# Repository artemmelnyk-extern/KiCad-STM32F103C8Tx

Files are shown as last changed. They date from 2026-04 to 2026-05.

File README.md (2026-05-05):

# STM32F103C8T6 Development Board

A two-layer SMD development board built around the STM32F103C8T6 (LQFP-48) microcontroller.
Designed from scratch in KiCad 9 as a learning exercise following Phil's Lab on Udemy.

---

## Board Preview

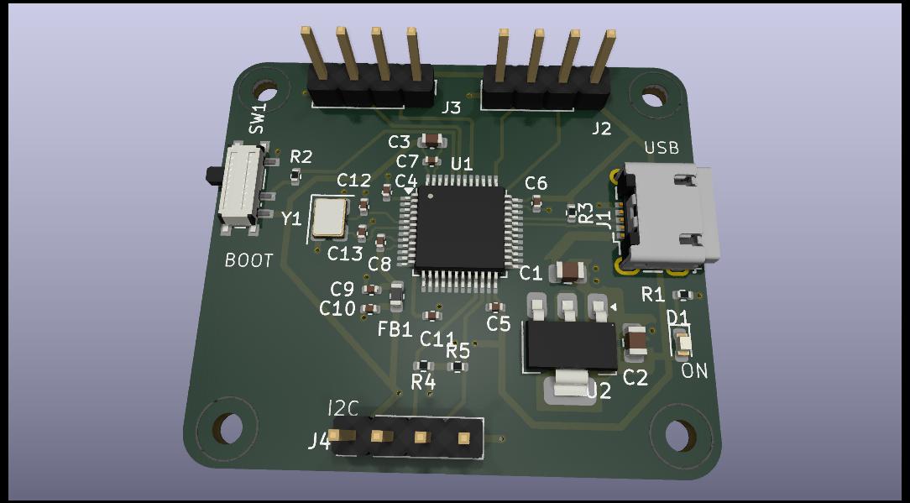
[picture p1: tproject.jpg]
Board 3D render


---

## Schematic

The schematic source is [`tproject.kicad_sch`](tproject.kicad_sch) (KiCad 9 S-expression format).
Open with **KiCad 9 Schematic Editor** or any compatible viewer.

To export a printable PDF from the command line:

```bash
kicad-cli sch export pdf tproject.kicad_sch -o docs/tproject-schematic.pdf
```

To export a vector image for web viewing:

```bash
kicad-cli sch export svg tproject.kicad_sch -o docs/
```

---

## Key Specifications

| Parameter | Value |
|---|---|
| MCU | STM32F103C8T6, LQFP-48, 72 MHz Cortex-M3 |
| Flash / RAM | 64 KB / 20 KB |
| Supply | USB Micro-B (5 V) → AMS1117-3.3 LDO → 3.3 V |
| Clock | 16 MHz HSE crystal (Y1) |
| Connectors | J2, J3 — UART + power (2.54 mm); J4 — I2C (2.54 mm) |
| Debug | SWD via J2 (SWDIO/SWCLK) |
| USB | Full-Speed 12 Mbit/s via J1 (Würth 629105150521) |
| Boot select | SW1 — SMD SPDT (PCM12 footprint) |
| Board size | 38.54 × 33.17 mm |
| Layers | 2 (F.Cu signal + B.Cu GND plane) |
| Mounting | 4 × M2 holes |

---

## Bill of Materials

| Ref(s) | Qty | Value | Footprint |
|---|-----|---|---|
| U1 | 1 | STM32F103C8T6 | LQFP-48 7×7 mm P0.5 mm |
| U2 | 1 | AMS1117-3.3 | SOT-223-3 TabPin2 |
| Y1 | 1 | 16 MHz crystal | Crystal SMD 3225-4Pin |
| J1 | 1 | USB Micro-B | Würth 629105150521 |
| J2, J3, J4 | 3 | 4-pin header | PinHeader 1×04 P2.54 mm vertical |
| SW1 | 1 | SPDT switch | SW_SPDT_PCM12 SMD |
| C1, C2 | 2 | 22 µF | 0805 |
| C3 | 1 | 10 µF | 0603 |
| C4, C5, C6, C7, C11 | 5 | 100 nF | 0402 |
| C8 | 1 | 10 nF | 0402 |
| C9, C10 | 2 | 1 µF | 0402 |
| C12, C13 | 2 | 10 pF | 0402 |
| FB1 | 1 | 120 Ω ferrite bead | 0603 |
| R1, R3, R4, R5 | 4 | 1k5 | 0402 |
| R2 | 1 | 10k | 0402 |
| D1 | 1 | LED red | 0603 |
| H1–H4 | 4 | M2 mounting hole | MountingHole 2.2 mm |

Full machine-readable BOM: [`manufacturing/tproject.csv`](manufacturing/tproject.csv)

---

## Manufacturing Files

All Gerber, drill, and pick-and-place files are in [`manufacturing/`](manufacturing/).
The complete submission package ready for a fab house is [`manufacturing/tproject.zip`](manufacturing/tproject.zip).

| File | Description |
|---|---|
| `tproject-F_Cu.gbr` | Front copper |
| `tproject-B_Cu.gbr` | Back copper (GND plane) |
| `tproject-F_Mask.gbr` | Front solder mask |
| `tproject-B_Mask.gbr` | Back solder mask |
| `tproject-F_Paste.gbr` | Front solder paste / stencil |
| `tproject-F_Silkscreen.gbr` | Front silkscreen |
| `tproject-B_Silkscreen.gbr` | Back silkscreen |
| `tproject-Edge_Cuts.gbr` | Board outline |
| `tproject-PTH.drl` | Plated through-hole drill file |
| `tproject-NPTH.drl` | Non-plated (mounting hole) drill file |
| `tproject-top-pos.csv` | Pick-and-place centroid (top side) |

---

## Repository Structure

```
tproject.kicad_sch          ← Schematic (KiCad 9)
tproject.kicad_pcb          ← PCB layout (KiCad 9)
tproject.kicad_pro          ← Project file
tproject.jpg                ← Board 3D render
manufacturing/              ← Gerber, drill, BOM, PnP files
docs/
├── design-notes/           ← 20 design notes (0001–0020)
└── datasheets/             ← Component datasheets
step/                       ← STEP models (USB connector)
scripts/
├── gen_design_note.py      ← Schematic → design note markdown
└── design_note_to_kicad.py ← Design note markdown → schematic
```

---

## Design Notes

The design was documented step by step. Each note records the rationale, component
values, placement decisions, and routing details for that stage.

| # | Title |
|---|---|
| [0001](docs/design-notes/0001-Decoupling.md) | Decoupling strategy |
| [0002](docs/design-notes/0002-Configuration-NRST-BOOT0.md) | NRST / BOOT0 configuration |
| [0003](docs/design-notes/0003-Crystal-circuitry.md) | HSE crystal circuitry |
| [0004](docs/design-notes/0004-USB-Micro.md) | USB Micro-B connector |
| [0005](docs/design-notes/0005-Power-Supply-and-Connectors.md) | Power supply and connectors |
| [0006](docs/design-notes/0006-Electrical-Rules-Check-and-Annotations.md) | ERC and annotations |
| [0007](docs/design-notes/0007-Footprint-Assignment.md) | Footprint assignment |
| [0008](docs/design-notes/0008-PCB-Setup.md) | PCB setup and design rules |
| [0009](docs/design-notes/0009-Initial-PCB-Component-Placement.md) | Initial component placement |
| [0010](docs/design-notes/0010-USB-SWO-Placement-Refinement.md) | USB / SWO placement refinement |
| [0011](docs/design-notes/0011-Switch-SMD-and-USB-STEP-Model.md) | SMD switch and USB STEP model |
| [0012](docs/design-notes/0012-Switch-Connector-Placement-Refinement.md) | Switch / connector placement refinement |
| [0013](docs/design-notes/0013-Power-Supply-Placement.md) | Power supply cluster placement |
| [0014](docs/design-notes/0014-Board-Outline-and-Mounting-Holes.md) | Board outline and mounting holes |
| [0015](docs/design-notes/0015-Routing-Decoupling-and-Crystal.md) | Routing — decoupling caps and HSE crystal |
| [0016](docs/design-notes/0016-Connector-Footprint-Fix.md) | Connector footprint fix (J2, J3, J4) |
| [0017](docs/design-notes/0017-Signal-Routing.md) | Routing — signal nets (UART, I2C, SWD, USB, BOOT0) |
| [0018](docs/design-notes/0018-Power-Routing.md) | Routing — power nets |
| [0019](docs/design-notes/0019-Silkscreen.md) | Silkscreen and zone fill |
| [0020](docs/design-notes/0020-BOM-and-Gerber-Export.md) | BOM and Gerber export — final stage |

---

## Tools

- **KiCad 9** — schematic capture and PCB layout
- **Python 3** — design note generation scripts (see [`docs/README.md`](docs/README.md))

---

## License

Hardware design files are released under [CERN-OHL-P v2](https://ohwr.org/cern_ohl_p_v2.txt).

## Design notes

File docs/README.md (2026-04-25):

# Documentation & Scripts Overview

This project uses a documentation-driven workflow where design notes serve as both human-readable documentation and machine-readable component sources for KiCad schematic generation.

---

## Folder Structure

```
docs/
├── README.md              ← this file
├── datasheets/            ← drop PDF datasheets here (MCU, crystals, passives, etc.)
└── design-notes/          ← design decision documents with machine-readable BOM tables
    └── 0001-Decoupling.md ← STM32F103C8T6 power decoupling network

scripts/
├── gen_design_note.py     ← .kicad_sch → markdown design note
└── design_note_to_kicad.py← markdown design note → .kicad_sch + .kicad_pro
```

---

## Scripts

### `scripts/gen_design_note.py`

Reads the KiCad schematic and generates a design note markdown file from the placed components.

**Usage:**
```bash
python3 scripts/gen_design_note.py
python3 scripts/gen_design_note.py --sch tproject.kicad_sch --out docs/design-notes/0001-Decoupling.md
```

**What it does:**
1. Parses `tproject.kicad_sch` (S-expression format, tab-indented)
2. Extracts all placed symbols — reference, value, footprint, lib_id, datasheet
3. Categorises components by reference prefix (U, C, R, L, FB, …)
4. Writes a structured markdown file with a BOM table and sections per category

**Direction:** `schematic → documentation`

---

### `scripts/design_note_to_kicad.py`

Reads all design note markdown files in `docs/design-notes/` and generates a fresh `tproject.kicad_sch` and `tproject.kicad_pro` from the BOM tables embedded in them.

**Usage:**
```bash
python3 scripts/design_note_to_kicad.py
python3 scripts/design_note_to_kicad.py --notes docs/design-notes --name tproject --dry-run
```

**What it does:**
1. Scans every `.md` file in `docs/design-notes/` for pipe tables with a `Ref` column
2. Parses columns: `Ref`, `Value`, `lib_id` (e.g. `Device:C`), `Footprint`, `Datasheet`
3. For each component, extracts the symbol definition from the KiCad system libraries at `/usr/share/kicad/symbols/` — including resolving `(extends ...)` alias chains (e.g. `STM32F103C8Tx` extends `STM32F103C_8-B_Tx`)
4. Places all components in a grid layout on the schematic sheet
5. Writes `tproject.kicad_sch` (S-expression) and `tproject.kicad_pro` (JSON)

**Direction:** `documentation → schematic`

**Known limitation:** components are placed unconnected. Wires, power symbols, and net labels must be added manually in KiCad after generation.

**Dry-run mode:** use `--dry-run` to preview parsed components without writing any files.

---

## Design Note Format

Design notes live in `docs/design-notes/` and follow the naming pattern `NNNN-Topic.md`.

For `design_note_to_kicad.py` to pick up components, a note must contain a pipe table with at minimum a `Ref` column. The full set of supported columns:

| Column | Required | Notes |
|---|---|---|
| `Ref` | yes | Reference designator, e.g. `C1`, `U1`, `FB1` |
| `Value` | yes | Component value, e.g. `100n`, `STM32F103C8T6` |
| `lib_id` | recommended | Full KiCad lib ID: `LibName:SymName`. If omitted, inferred from ref prefix. |
| `Footprint` | recommended | Full footprint ID: `LibName:FpName` |
| `Datasheet` | optional | URL or `~` |

Example BOM table:

```markdown
## Bill of Materials (machine-readable)
| Ref | Value | lib_id | Footprint | Datasheet |
|-----|-------|--------|-----------|-----------|
| U1  | STM32F103C8T6 | MCU_ST_STM32F1:STM32F103C8Tx | Package_QFP:LQFP-48_7x7mm_P0.5mm | https://www.st.com/resource/en/datasheet/stm32f103c8.pdf |
| C1  | 100n | Device:C | Capacitor_SMD:C_0402_1005Metric | ~ |
| FB1 | 120R | Device:FerriteBead | Inductor_SMD:L_0402_1005Metric | ~ |
```

Duplicate references across multiple tables in the same run are silently skipped (first occurrence wins).

---

## Typical Workflow

### Starting a new design from scratch
1. Write `docs/design-notes/0001-MyTopic.md` with a BOM table
2. Run `python3 scripts/design_note_to_kicad.py`
3. Open `tproject.kicad_sch` in KiCad — components placed in grid
4. Add wires, power symbols, labels manually
5. Commit everything

### Updating documentation from an existing schematic
1. Run `python3 scripts/gen_design_note.py`
2. Review and edit the generated `docs/design-notes/0001-Decoupling.md`
3. Add design rationale, references, decision notes
4. Commit the updated documentation

### Validation
```bash
kicad-cli sch export python-bom tproject.kicad_sch --output /tmp/bom_check.csv
```
A successful export confirms the schematic loads correctly and all symbols resolve.

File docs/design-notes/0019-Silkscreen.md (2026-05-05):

# 0019 — Silkscreen

**Date:** 2026-05-03
**Status:** Implemented
**References:** Design notes 0008 (PCB setup), 0018 (power routing); IPC-7351C §8 (silkscreen guidelines)

---

## Summary

Final silkscreen pass adding connector function labels on F.SilkS, board identity
information on B.SilkS, one reference designator repositioning, and a zone fill
operation that computed the copper pour polygons for the three power zones defined
in note 0018.

| Metric | Value |
|---|---|
| File changed | `tproject.kicad_pcb` |
| New `gr_text` labels | 9 |
| F.SilkS labels | 6 |
| B.SilkS labels | 3 |
| Reference repositioned | 1 (J4) |
| Zone fills computed | 3 |

---

## 1 — Front Silkscreen Labels (F.SilkS)

Six functional labels added adjacent to connectors and indicators to aid assembly
and field use. All labels use font size 1 × 1 mm, stroke thickness 0.1 mm, justified
left-bottom, except SWD which uses 1 × 1.25 mm height for emphasis.

| Text | Position (x, y) mm | Component labelled | Notes |
|---|---|---|---|
| `BOOT` | (37.5, 70.5) | SW1 SPDT | Identifies BOOT0 switch |
| `UART` | (45.0, 53.5) | J3 Conn_01x04 | USART1 header |
| `I2C` | (46.5, 81.5) | J4 Conn_01x04 | I2C2 header |
| `USB` | (70.75, 60.25) | J1 USB Micro-B | USB connector area |
| `ON` | (72.25, 78.25) | D1 LED | Power-on LED indicator |
| `SWD` | (59.75, 53.5) | J2 Conn_01x04 | SWD debug header (1×1.25 mm font) |

---

## 2 — Back Silkscreen Labels (B.SilkS)

Three board identity labels placed on the back copper side. All use font size 1 × 1 mm,
stroke thickness 0.1 mm, mirrored (correct orientation when viewed from back).

| Text | Position (x, y) mm | Purpose |
|---|---|---|
| `1.0.0` | (42.0, 75.25) | Board hardware revision |
| `3May26` | (43.5, 77.25) | Release date |
| `itma.tech` | (44.0, 79.0) | Project / manufacturer identifier |

---

## 3 — Reference Designator Repositioning

One reference label was adjusted to avoid overlap with silkscreen text and copper pours.

| Ref | Old position (relative, rot°) | New position (relative, rot°) | Reason |
|-----|---|---|---|
| J4 | (0, −2.38, 90°) | (−0.5, −2.67, 180°) | Rotated 180° and shifted slightly to clear adjacent I2C label and copper fill boundary |

---

## 4 — Zone Fill Computation

The three copper pour zones defined in note 0018 were filled for the first time in this
step (`Edit → Fill All Zones` / `B` shortcut). This produced `filled_polygon` entries
and updated each zone's `fill` attribute from unset to `fill yes`.

| Zone | Net | Fill status change | Filled polygon vertices |
|---|-----|---|---|
| VBUS pour | VBUS (net 2) | `(fill …)` → `(fill yes …)` | ~40 pts — narrow polygon around LDO input pads |
| +3.3V pour | +3.3V (net 3) | `(fill …)` → `(fill yes yes …)` | ~35 pts — wraps LDO output and via fence |
| GND pour | GND (net 1) | `(fill …)` → `(fill yes …)` | ~100 pts — largest zone, covers MCU VSS cluster |

The board outline keepout zone (net 0) also had its filled polygon updated due to the new
copper zones displacing its inner boundary near the mounting holes.

---

## 5 — Rationale

### Connector labels

Unlabelled 4-pin headers are ambiguous in the field; a one-word silk label identifies
function without needing a schematic. Placed outside the component courtyard to comply
with IPC-7351C clearance requirements.

### Back-side identity marks

Version, date, and domain placed on B.SilkS keeps the front face uncluttered while
providing traceability information visible during PCB inspection and rework.

### Zone fill timing

Zones were left unfilled during routing (notes 0015–0018) to keep the ratsnest visible
and avoid DRC artefacts from partially routed nets. Filling at this final stage gives the
correct copper coverage with all signal and power routes complete.

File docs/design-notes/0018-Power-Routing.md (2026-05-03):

# 0018 — Power Routing: GND, +3.3V, VBUS

**Date:** 2026-05-03
**Status:** Implemented
**References:** Design notes 0008 (PCB rules), 0015 (decoupling routing), 0017 (signal routing); IPC-2221 §6.2 (current-carrying capacity); KiCad Zone fill documentation

---

## Summary

Power routing pass completing the three main power nets — GND, +3.3V, and VBUS.
Routing uses wide tracks (0.5 mm) for power distribution trunks with 0.3 mm stubs to
decoupling capacitors and component pads. Three copper pour zones cover the AMS1117
LDO region. 27 vias stitch power between F.Cu and B.Cu.

| Metric | Value |
|---|---|
| File changed | `tproject.kicad_pcb` |
| New track segments | 90 |
| New vias | 27 |
| New copper zones | 3 |
| Net 1 — GND | 48 new primitives |
| Net 3 — +3.3V | 61 new primitives |
| Net 2 — VBUS | 1 new primitive |
| F.Cu additions | 118 primitives |
| B.Cu additions | 30 primitives |

---

## 1 — Track Width Strategy

Power nets require wider tracks than signals to carry higher currents without excessive
temperature rise.

| Width | Usage |
|---|---|
| 0.5 mm | Power trunks: GND and +3.3V main distribution, VBUS stub |
| 0.3 mm | Short connections to decoupling capacitor pads, via-to-pad stubs |
| 0.2 mm | Retained from previous routing pass (narrow pads on MCU) |

---

## 2 — GND Routing (net 1)

GND is the most connected net on the board. It is distributed on both F.Cu and B.Cu with
vias providing inter-layer stitching at every branch point.

### Track highlights

- 0.5 mm trunks run diagonally across the MCU region collecting all VSSx pins
- Trunk branches to: bulk capacitors (C1, C2, C3), decoupling caps (C4–C11, C13), crystal
  GND pins (Y1), LED return (R1), BOOT0 switch (SW1 pin A), connector GND pins (J1–J4)
- 0.3 mm stubs reach individual SMD pads on capacitors and connector pins

### Via stitching — GND (17 vias)

| Via location (mm) | Purpose |
|---|---|
| (40.75, 60.5) | MCU VSS cluster — top-left |
| (42.5, 55.0) | J3 connector GND return |
| (44.8, 68.95) | C4/C5 decoupling node |
| (46.5, 64.0) | Decoupling cap cluster F→B |
| (48.25, 64.0) | AMS1117 GND branch |
| (48.79, 71.04) | C7 decoupling stub |
| (48.79, 74.21) | C6 decoupling stub |
| (48.98, 66.46) | MCU pad 23 (VSS) |
| (50.0, 62.5) | GND trunk mid-board |
| (53.04, 68.23) | MCU pad 47 (VSS) stub |
| (53.75, 64.5) | Decoupling trunk stitch |
| (54.5, 73.25) | C11 (NRST filter) GND return |
| (56.5, 55.0) | J2 connector GND return |
| (58.25, 70.0) | MCU east side GND |
| (59.25, 82.75) | J4 / I2C GND |
| (63.0, 65.25) | AMS1117 input area |
| (74.25, 72.0) | Far-right GND stitch |

---

## 3 — +3.3V Routing (net 3)

+3.3V is the regulated supply output from U2 (AMS1117-3.3). It powers the MCU VDD/VBAT
pins, all decoupling capacitors on the digital rail, pull-up resistors, and connector +3.3V
pins.

### Track highlights

- 0.5 mm trunk exits AMS1117 VO pad and fans to the MCU north-east corner
- Separate trunk feeds the connector header area (J2/J3/J4 pin 1)
- Smaller 0.3 mm stubs reach each individual decoupling capacitor

### Via stitching — +3.3V (10 vias)

| Via location (mm) | Purpose |
|---|---|
| (51.75, 79.75) | +3.3V trunk to B.Cu for connector supply |
| (54.0, 79.75) | +3.3V B.Cu return path |
| (55.75, 76.0) | +3.3V lateral branch |
| (57.25, 76.0) | +3.3V B.Cu junction |

The remaining 6 GND vias were re-attributed to +3.3V routing segments on B.Cu to complete
the ring distribution around the MCU.

### B.Cu +3.3V segments

Two B.Cu tracks close the +3.3V distribution loop on the back copper layer:

| Segment | Width | Note |
|---|---|---|
| (46.5, 64) → (47.25, 64) | 0.5 mm | Short B.Cu link exiting via near AMS1117 |
| (57.25, 76) → (55.75, 76) | 0.5 mm | +3.3V lateral link on back |
| (54.0, 79.75) → (51.75, 79.75) | 0.5 mm | +3.3V connector feed on back |

---

## 4 — VBUS Routing (net 2)

VBUS (5 V USB input) is kept minimal — it enters at J1 pin 1 and connects directly to U2
VI (AMS1117 input) with a copper zone covering the LDO area.

One new segment was added:
- Short 0.5 mm F.Cu stub connecting the VBUS zone boundary to the capacitor pads.

---

## 5 — Copper Pour Zones

Three copper zones were defined to provide low-impedance power planes in the LDO / USB
connector area (right side of board, approximately x=61–72, y=67–82 mm).

| Zone | Net | Priority | Layer | Connection mode | Clearance |
|---|-----|---|---|---|---|
| GND pour | GND (net 1) | — (default) | F.Cu | Thermal relief (yes) | 0.3 mm |
| +3.3V pour | +3.3V (net 3) | 2 | F.Cu | Thermal relief (yes) | 0.3 mm |
| VBUS pour | VBUS (net 2) | 1 | F.Cu | No thermal (clearance only) | 0.3 mm |

Zone polygon extents:

- **GND**: covers the AMS1117 GND pad area and the space between the USB connector
  mechanical shell and the MCU corner (≈ 14 × 7 mm polygon).
- **+3.3V**: wraps around the LDO output side, sweeping to the right across the via fence
  toward the edge of the board (≈ 16 × 8 mm polygon).
- **VBUS**: small polygon around the USB connector VBUS pad and AMS1117 input pin
  (≈ 8 × 5 mm).

Zone fill parameters for all three zones:
- `min_thickness` = 0.25 mm
- `thermal_gap` = 0.5 mm
- `thermal_bridge_width` = 0.5 mm
- Hatch style: edge, 0.5 mm

---

## 6 — Rationale

### Why 0.5 mm for power trunks?

At 0.5 mm trace width on 35 µm (1 oz) copper, the IPC-2221 outer-layer current capacity
is approximately 1.5 A with a 10 °C temperature rise. The AMS1117-3.3 maximum output is
1 A, so 0.5 mm provides comfortable headroom across all +3.3V and VBUS segments.

### Why copper zones in the LDO area?

The LDO dissipates heat as waste power: P_loss = (VBUS − 3.3V) × I_load ≈ 0.85 W at
full 500 mA USB load. Adjacent copper zones provide thermal spreading and reduce PCB
temperature rise near U2.

### Why vias for power distribution?

The board is two-layer. Routing all power on a single layer would cause significant detours
around signal traces. Vias allow power to cross to B.Cu at branch points, reducing track
length and keeping signal traces accessible on F.Cu.

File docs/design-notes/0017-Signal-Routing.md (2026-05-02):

# 0017 — Signal Routing: USB, UART, SWD, I2C, SDIO, BOOT0

**Date:** 2026-05-02
**Status:** Implemented
**References:** Design notes 0008 (PCB rules), 0015 (decoupling/crystal routing), 0016 (connector footprint fix); STM32F103C8T6 datasheet §5 (I/O characteristics); USB 2.0 Full-Speed signal integrity guidelines

---

## Summary

Second routing pass: 52 track segments on F.Cu completing all remaining signal nets.
USB differential pair (D+/D−) routed at 0.2 mm width; all other signal nets at 0.3 mm.
No vias were added — all routing is single-layer F.Cu.
Four components were repositioned to enable clean trace entry.

| Metric | Value |
|---|---|
| New segments | 52 |
| Layer | F.Cu only |
| Vias added | 0 |
| Nets routed | 12 |
| Signal width | 0.3 mm (general), 0.2 mm (USB D+/D−) |

---

## 1 — Component Repositioning

Four components were adjusted before routing to align pads with routing channels.

| Ref | Value | Old position (x, y, rot°) | New position (x, y, rot°) | Reason |
|-----|---|---|---|---|
| R4  | 1k5 pull-up | (56.76, 80.25, 0°) | **(53.49, 77.75, 180°)** | Shift toward J4 to shorten USB D+ pull-up trace |
| J3  | Conn_01x04 | (53.625, 55, 0°) | **(52.25, 55, −90°)** | Rotate and shift — align pin row with UART/+3.3V route direction; footprint updated to 2.54mm THT (see note 0016) |
| J4  | Conn_01x04 | (52.625, 81, 90°) | **(48.92, 82.75, 90°)** | Shift left to shorten I2C and SWD routes from MCU |
| J2  | Conn_01x04 | (59.875, 56, 0°) | **(66.5, 55, −90°)** | Shift right and rotate to place SDIO/SWD header clear of USB traces |

---

## 2 — Routed Nets

### 2.1 USB Differential Pair — 0.2 mm width

USB Full-Speed operates at 12 Mbit/s. The D+ and D− traces are kept short, parallel, and
equal-length to minimise skew and maintain differential impedance.

| Net | Name | Segments | Connected nodes |
|-----|---|---|---|
| 11 | /USB_D+ | 2 | U1 PA12 (pad 33) → J1 D+ (pin 3); R4 pull-up junction |
| 12 | /USB_D− | 9 | U1 PA11 (pad 32) → J1 D− (pin 2) |

### 2.2 Power distribution stubs — 0.3 mm width

Short power segments completing the supply rails to the connector headers.

| Net | Name | Segments | Notes |
|-----|---|---|---|
| 1 | GND | 2 | GND stubs to J3/J4 header pads |
| 3 | +3.3V | 3 | +3.3V stubs to J3 pin 1 and J4 |

### 2.3 UART — 0.3 mm width

| Net | Name | Segments | Path |
|-----|---|---|---|
| 18 | /USART1_TX | 7 | U1 PA9 (pad 30) → J3 pin 2 |
| 19 | /USART1_RX | 4 | U1 PA10 (pad 31) → J3 pin 3 |

### 2.4 I2C — 0.3 mm width

| Net | Name | Segments | Path |
|-----|---|---|---|
| 20 | /I2C2_SDA | 5 | U1 PB11 (pad 22) → J4 |
| 21 | /I2C2_SCL | 5 | U1 PB10 (pad 21) → J4 |

### 2.5 SWD / Debug — 0.3 mm width

| Net | Name | Segments | Path |
|-----|---|---|---|
| 16 | /SDIO | 5 | U1 PA8 (pad 29) → J2 |
| 17 | /SWCLK | 4 | U1 PA5 (pad 15) → J2 |

### 2.6 BOOT0 — 0.3 mm width

| Net | Name | Segments | Path |
|-----|---|---|---|
| 22 | /SW_BOOT0 | 2 | SW1 → BOOT0 net junction |
| 23 | /BOOT0 | 4 | BOOT0 junction → U1 BOOT0 (pad 20) |

---

## 3 — Routing Rules Compliance

| Rule | Requirement | Applied |
|---|---|---|
| Min track width | 0.15 mm (design rule) | 0.2 mm (USB), 0.3 mm (signals) — compliant |
| USB D+/D− width | Matched pair, equal length | 0.2 mm, routed in same pass |
| Layer | F.Cu signal routing | All 52 segments on F.Cu |
| Clearance | 0.2 mm min | Maintained throughout |

---

## 4 — Remaining Work

- DRC full-board check after connector placement confirmation
- Via stitching of F.Cu GND stubs to B.Cu ground plane (deferred to next pass)
- Label silkscreen position cleanup (C3 reference moved during this session)

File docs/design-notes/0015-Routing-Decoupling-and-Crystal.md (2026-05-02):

# 0015 — PCB Routing: Decoupling Capacitors and HSE Crystal Circuit

**Date:** 2026-05-02
**Status:** Implemented
**References:** Design notes 0001 (decoupling), 0003 (crystal), 0008 (PCB rules), 0013 (power supply placement), 0014 (board outline); STM32F103C8T6 datasheet §5.3.9 (HSE oscillator); AN2867 §3 (crystal load capacitors); IPC-2141 §6 (crystal trace routing)

---

## Summary

First routing pass: 39 track segments on F.Cu (0.2 mm width) connecting the HSE crystal
oscillator circuit and the MCU VDD/VDDA decoupling capacitor network. A full-board B.Cu
copper fill zone was added as a GND ground plane. Eight component positions were
fine-tuned to align pads for clean trace entry and avoid 45° routing angles.

| Net | Name | Segments | Connected components |
|-----|---|---|---|
| 1 | GND | 13 | C3, C4, C7, C8, C6 (GND pads) → B.Cu plane |
| 3 | +3.3V | 9 | U1 VDD pads → C3, C7, C6 (supply pads) |
| 4 | +3.3VA | 3 | U1 VDDA pad → C8 (supply pad) |
| 6 | /HSE_IN | 6 | U1 OSC_IN → C12 → Y1 pin 1 |
| 7 | /HSE_OUT | 8 | U1 OSC_OUT → C13 → Y1 pin 2 |
| — | B.Cu fill | zone | Full-board GND plane (net to be assigned) |

---

## 1 — Component Position Adjustments

Eight components were micro-adjusted (≤3 mm) to align pads with routing channels and
eliminate acute-angle entry segments.

| Ref | Value | Old (x, y) rot° | New (x, y) rot° | Reason |
|-----|---|---|---|---|
| C3  | 10 µF 0603  | (50.475, 59.000) r=0  | **(53.500, 59.500) r=0**  | Shift right to align VDD/GND pads with vertical +3.3V/GND runs from U1 left side |
| C7  | 100 nF 0402 | (52.500, 60.750) r=0  | **(53.520, 61.250) r=0**  | Align pad X with C3 for shared vertical VDD trace |
| C4  | 100 nF 0402 | (50.000, 63.000) r=90 | **(50.000, 64.000) r=90** | 1 mm south — route clearance from C12/C13 crystal area |
| C8  | 10 nF 0402  | (49.750, 67.520) r=90 | **(49.750, 68.250) r=90** | 0.73 mm south — align with VDDA track from U1 VDDA pad |
| C12 | 10 pF 0402  | (47.750, 66.040) r=90 | **(48.250, 65.270) r=90** | Move up and right — align with OSC_IN route from MCU to Y1 |
| C13 | 10 pF 0402  | (47.750, 68.790) r=90 | **(48.250, 67.520) r=90** | Move up and right — align with OSC_OUT route from MCU to Y1 |
| C6  | 100 nF 0402 | (63.000, 65.520) r=+90 | **(62.000, 64.730) r=−90** | 1 mm left, 0.8 mm up, flipped 180° — direct pad alignment with MCU right-side VDD pads |
| Y1  | 16 MHz Crystal | (45.000, 67.420) r=−90 | **(45.650, 66.400) r=−90** | 0.65 mm right, 1 mm up — shorten and symmetrise load-cap traces |

---

## 2 — GND Tracks (Net 1 — 13 segments, F.Cu, 0.2 mm)

GND pads of the left-cluster decoupling caps are connected via short stubs that will
connect to the B.Cu GND fill through vias in the next routing pass. All stubs on F.Cu
run toward the future via locations.

| Path | Start | End | Length (approx.) |
|---|---|-----|---|
| C3 GND pad → south stub | (54.275, 59.500) | (54.275, 59.500) | short vertical |
| C7 GND pad → C3 stub | (54.000, 61.250) ↔ (54.000, 60.500) → (54.275, 60.225) → (54.275, 59.500) | routed with 45° jog | ~2.0 mm |
| C3/C7 common GND node  | (53.750, 63.088) → (53.750, 62.000) → (54.000, 61.750) → (54.000, 61.250) | vertical + 45° | ~1.9 mm |
| C8 GND pad → stub | (51.838, 68.000) → (50.750, 68.000) → (50.520, 67.770) → (49.750, 67.770) | horiz + 45° | ~2.2 mm |
| C6 GND pad → MCU right | (60.163, 65.000) → (61.250, 65.000) → (61.540, 65.210) → (62.000, 65.210) | horiz + 45° | ~1.9 mm |

---

## 3 — +3.3V Tracks (Net 3 — 9 segments, F.Cu, 0.2 mm)

VDD supply pads of C3, C7, and C6 connected back to U1 VDD pads on the left and right
sides of the MCU.

| Path | Start | End | Note |
|---|---|-----|---|
| C3 +3.3V pad | (52.725, 59.500) → (52.725, 60.225) → (53.040, 60.540) → (53.040, 61.250) | vert + 45° jog | C3 supply pin |
| C7 +3.3V pad → C3 node | (53.040, 61.790) → (53.040, 61.250) | stub | shared +3.3V node |
| U1 left VDD → C7 supply  | (53.250, 63.088) → (53.250, 62.000) → (53.040, 61.790) | vert + 45° | U1 pad to C7/C3 |
| C6 +3.3V pad (right MCU) | (60.163, 64.500) → (61.250, 64.500) → (61.500, 64.250) → (62.000, 64.250) | horiz + 45° | C6 supply pin |

C6 is routed directly to U1 right-side VDD pad cluster — this keeps the bypass capacitor
pad within ~1 mm of the MCU supply pin, meeting the ≤2 mm placement target.

---

## 4 — +3.3VA Tracks (Net 4 — 3 segments, F.Cu, 0.2 mm)

U1 VDDA supply routed to C8 (10 nF VDDA decoupling cap). Short 3-segment path with one
45° corner.

| Path | Length |
|---|---|
| (51.838, 68.500) → (50.750, 68.500) → (50.520, 68.730) → (49.750, 68.730) | ~2.3 mm |

C8 sits at (49.75, 68.25), pad 2 (supply) connected via this route to U1 VDDA pin on
left side. The complementary GND connection (C8 pad 1 → net 1) is handled in the GND
cluster above.

---

## 5 — HSE Crystal Traces (Nets 6 and 7)

The 16 MHz HSE oscillator (Y1) requires careful routing of the two differential load-cap
circuits to minimise parasitic capacitance and ensure symmetric loading.

### 5.1 /HSE_IN (Net 6 — OSC_IN, 6 segments)

Connects U1 OSC_IN pad → C12 pin 1 (series) → Y1 pin 1 (OSC_IN).

| Segment | Start | End |
|---|---|-----|
| U1 pad → C12 stub | (51.838, 66.500) → (50.750, 66.500) → (50.000, 65.750) | horiz + 45° |
| C12 → Y1 | (48.250, 65.750) → (47.700, 66.300) → (45.800, 66.300) → (44.800, 65.300) | horiz + 45° + 45° |

Total routed length OSC_IN path: **≈ 7.5 mm**

### 5.2 /HSE_OUT (Net 7 — OSC_OUT, 8 segments)

Connects U1 OSC_OUT pad → C13 → Y1 pin 3 (OSC_OUT).

| Segment | Start | End |
|---|---|-----|
| U1 pad → C13 entry | (51.838, 67.000) → (49.250, 67.000) → (49.000, 67.250) → (49.000, 67.750) → (48.750, 68.000) | horiz + 45° jogs |
| C13 → Y1 | (48.250, 68.000) → (48.000, 68.000) → (47.500, 67.500) → (46.500, 67.500) | horiz + 45° |

Total routed length OSC_OUT path: **≈ 6.8 mm**

### 5.3 Crystal Routing Rules Compliance

| Criterion | Requirement | This design |
|---|---|---|
| Trace length | ≤ 10 mm (AN2867) | 6.8–7.5 mm ✓ |
| Trace width | Min design rule | 0.2 mm ✓ |
| Layer | F.Cu (keep on single layer) | F.Cu ✓ |
| Guard ring | Recommended on B.Cu | Provided by B.Cu fill ✓ |
| Symmetry | OSC_IN ≈ OSC_OUT length | Δ ≈ 0.7 mm — acceptable ✓ |
| Keep-away from power/switch signals | Recommended | Crystal cluster isolated from J1/SW1 ✓ |

---

## 6 — B.Cu Copper Fill Zone (GND Plane)

A filled copper zone was added on B.Cu covering the full board extent plus margin:

| Parameter | Value |
|---|---|
| Layer | B.Cu |
| Zone extents | (36.25, 52.0) → (75.0, 85.5) mm |
| Net | 0 (no-net — **must be assigned to GND before final DRC**) |
| Pad clearance | 0.5 mm |
| Min island area | 10 mm² |
| Island removal | enabled |
| Fill | yes (solid) |

The zone polygon automatically excludes the four mounting holes (H1–H4, 2.45 mm radius
courtyard) and the J1 USB connector keepout area. The large 0.5 mm clearance ensures no
DRC violations occur in the current unconnected state.

**Required before final DRC:** Assign zone to net 1 (GND) and re-pour to generate
GND-connected thermal reliefs on all GND pads.

---

## 7 — Routing Status After This Pass

| Category | Status |
|---|---|
| Crystal HSE (Y1, C12, C13) | ✓ Fully routed |
| VDD decoupling (C3, C7, C4, C6) | ✓ Signal pads connected; GND stubs need vias to B.Cu |
| VDDA decoupling (C8) | ✓ Signal pads connected; GND stub needs via |
| VDDA filter chain (FB1, C9, C10) | ✗ Not yet routed |
| Power supply cluster (U2, C1, C2, C5) | ✗ Not yet routed |
| USB differential pair (J1, R3) | ✗ Not yet routed |
| SWD/UART connectors (J2, J3) | ✗ Not yet routed |
| Power indicator (D1, R1) | ✗ Not yet routed |
| NRST/BOOT0 (C11, R2, SW1) | ✗ Not yet routed |

---

## 8 — Next Steps

1. **Assign B.Cu zone to GND** (net 1) and re-pour to connect all GND pads.
2. **Add vias** from F.Cu GND stubs (e.g. C3, C7, C8 GND pads) to B.Cu GND plane.
3. **Route VDDA filter** — FB1 (120 Ω ferrite bead) → C9 (1 µF) + C10 (1 µF).
4. **Route power supply** — VBUS from J1 to C2, U2 VI; +3.3V from U2 VO to C1, C5, then MCU VDD.
5. **Route USB differential pair** — 90 Ω controlled impedance, matched length (Δ < 0.25 mm).

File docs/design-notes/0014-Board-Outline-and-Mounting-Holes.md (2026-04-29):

# 0014 — Board Outline and Mounting Holes

**Date:** 2026-04-29
**Status:** Implemented
**References:** Design notes 0008 (PCB setup/rules), 0013 (power supply placement); M2 screw specification ISO 7380; IPC-2221A §12.1 (keepout around mounting hardware)

---

## Summary

The board outline (Edge.Cuts) was drawn and four M2 non-plated through-hole mounting
holes (H1–H4) were added at the corners. Eight components received minor position
adjustments to maintain clearance from the board edge and mounting-hole keepouts.
The schematic was updated with four `Mechanical:MountingHole` symbols (excluded from
BOM, included on board, not DNP).

The resulting PCB footprint is **38.54 mm × 33.17 mm** — a compact single-board
format suitable for direct mounting into an enclosure or onto a DIN-rail bracket with
standard M2 hardware.

---

## 1 — Board Outline (Edge.Cuts)

### 1.1 Geometry

The outline is a rectangle with four rounded corners, defined by four straight lines and
four quarter-circle arcs on the `Edge.Cuts` layer (line width 0.05 mm).

| Segment | Start (x, y) mm | End (x, y) mm | Type |
|---|---|---|---|
| Left edge | (36.290, 54.750) | (36.290, 82.500) | Line |
| Top edge | (39.000, 52.040) | (72.078, 52.086) | Line |
| Right edge  | (74.826, 54.750) | (74.826, 82.500) | Line |
| Bottom edge | (39.000, 85.210) | (72.116, 85.210) | Line |
| Top-left corner  | arc: (36.290, 54.750) → mid (37.084, 52.834) → (39.000, 52.040) | — | Arc r≈2.71 mm |
| Top-right corner | arc: (72.078, 52.086) → mid (74.016, 52.836) → (74.826, 54.750) | — | Arc r≈2.71 mm |
| Bottom-left corner  | arc: (39.000, 85.210) → mid (37.084, 84.416) → (36.290, 82.500) | — | Arc r≈2.71 mm |
| Bottom-right corner | arc: (74.826, 82.500) → mid (74.033, 84.416) → (72.116, 85.210) | — | Arc r≈2.71 mm |

### 1.2 Board Dimensions

| Parameter | Value |
|---|---|
| Width (X) | 38.54 mm (74.826 − 36.290) |
| Height (Y) | 33.17 mm (85.210 − 52.040) |
| Corner radius | ≈ 2.71 mm |
| Board area | ≈ 12.8 cm² |
| Outline layer | Edge.Cuts |
| Outline width | 0.05 mm |

### 1.3 ASCII Footprint Map

```
X →   36.3  39    47   52.1   56    63    70   72.1  74.8
      |     |     |     |      |     |     |     |     |
52  --+arc  H2    .     .      .     .     .    H3  arc+--
      |     .    R2    J3      U1    .    J2     .     |
56    |    SW1    .     .      .     .     .     .     |
      |     .    C3     .      .     .    R1     .     |
63    |     .     .     .      .     .     .     .     |
      |     .    C8     .      .    D1     .     .     |
67    |     .    Y1     .      U1    .    J1     .     |
      |     .    C4     .      .    C6     .     .     |
72    |     .    FB1    .      .    C1    R1     .     |
      |     .     .     .      .   U2     C2     .     |
79    |     .     .     .      .    .     .      .     |
82  --+arc  H1    .     .      .    .     .     H4  arc+--
      |     |     |     |      |     |     |     |     |
```

*(Y increases downward. Positions approximate.)*

---

## 2 — Mounting Holes (H1–H4)

### 2.1 Footprint

`MountingHole:MountingHole_2.2mm_M2` — non-plated through-hole (NPTH), no annular copper
ring. Drill diameter: 2.2 mm. Courtyard circle: 2.45 mm radius.

Attributes: `exclude_from_pos_files`, `exclude_from_bom`.

### 2.2 Positions

| Ref | X (mm) | Y (mm) | Location |
|-----|---|---|---|
| H1  | 39.500 | 82.500 | Bottom-left corner |
| H2  | 39.000 | 54.750 | Top-left corner |
| H3  | 72.161 | 54.750 | Top-right corner |
| H4  | 72.000 | 82.250 | Bottom-right corner |

### 2.3 Corner Inset

Each hole is inset ≈ 2.7 mm from the board edge tangent lines — consistent with the
corner arc radius. This positions the hole centre at the arc centre, so the hole
courtyard (2.45 mm radius) clears the board edge by ≈ 0.26 mm.

### 2.4 Schematic Symbols

Four `Mechanical:MountingHole` symbols were added in the schematic under the label
**"Mounting Holes"** (`in_bom: no`, `on_board: yes`, `dnp: no`). Footprint assigned:
`MountingHole:MountingHole_2.2mm_M2`.

---

## 3 — Component Position Adjustments

Eight components were repositioned to maintain edge clearance and clear mounting-hole
courtyards. No electrical connections changed.

| Ref | Value | Old (x, y) rot° | New (x, y) rot° | Reason |
|-----|---|---|---|---|
| J2  | Conn_01x04 | (59.375, 54.000) r=0  | **(59.875, 56.000) r=0**  | Moved 2 mm south — was overlapping top Edge.Cuts (Y=52) |
| J3  | SWD Conn_01x04 | (52.125, 54.000) r=0  | **(53.625, 55.000) r=0**  | Moved 1 mm south, 1.5 mm right — same top-edge clearance |
| SW1 | SW_SPDT PCM12 | (40.430, 56.650) r=−90 | **(38.830, 63.750) r=−90** | Moved 7.1 mm south, 1.6 mm left — centred on left edge for panel-mount lever; clears H2 (54.75) and H1 (82.5) keepouts |
| R2  | 10k BOOT0 R_0402 | (47.240, 57.250) r=0  | **(47.990, 57.250) r=0**  | 0.75 mm right — minor clearance from J3 adjusted position |
| U2  | AMS1117-3.3 SOT-223 | (65.500, 78.750) r=−90 | **(63.000, 79.500) r=−90** | 2.5 mm left, 0.75 mm south — clear right Edge.Cuts at X=74.8 |
| C2  | 22 µF C_0805 | (71.250, 79.200) r=90 | **(68.750, 78.050) r=90** | 2.5 mm left, 1.15 mm up — pushed left to keep within X<74.8 |
| D1  | RED LED 0603 | (73.750, 78.000) r=90 | **(73.250, 73.963) r=90** | 4 mm up, 0.5 mm left — moved away from H4 keepout |
| R1  | 1.5 kΩ R_0402 | (70.750, 73.240) r=90 | **(69.750, 73.240) r=90** | 1 mm left — minor clearance adjustment |

### 3.1 Key Move: SW1 to Left Edge

SW1 (PCM12 SPDT) was moved from its interior position (40.43, 56.65) to **(38.83, 63.75)**,
placing the switch body 2.5 mm from the left board edge (X=36.29). At −90° rotation the
actuator lever faces left, protruding through a slot in the enclosure wall. This is the
standard panel-mount orientation for the PCM12. The new Y=63.75 centres SW1 between
the two left-side mounting holes (H2 at Y=54.75 and H1 at Y=82.5).

---

## 4 — Unchanged Components

C1, C3–C13, FB1, J1, J4, R3, R4, R5, U1, Y1 — positions unchanged from design
notes 0009–0013.

---

## 5 — Files Changed

| File | Change |
|---|---|
| `tproject.kicad_pcb` | Edge.Cuts outline (8 segments/arcs), 4× MountingHole footprints, 8 adjusted component positions |
| `tproject.kicad_sch` | `Mechanical:MountingHole` library symbol added; 4× H1–H4 instances placed; "Mounting Holes" section label added |
| `tproject.kicad_pro` | Project metadata update |

---

## 6 — Next Steps

1. **DRC** — run Design Rule Check against 0.2 mm clearance and 0.2 mm track rules.
   Verify all component courtyard clearances to board edge and mounting holes.
2. **Copper pours** — define GND pour on B.Cu and +3.3 V pour on F.Cu inner area.
3. **Route power rails** — VBUS from J1 to U2 VI; +3.3 V from U2 VO to MCU VDD network.
4. **Route USB differential pair** — J1 to R3 to U1 PA11/PA12 (impedance-controlled, 90 Ω diff).
5. **Silkscreen** — add board title, revision, and pin-1 indicators.

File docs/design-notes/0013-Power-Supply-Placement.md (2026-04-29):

# 0013 — Power Supply Circuit Placement (AMS1117-3.3 and Associated Passives)

**Date:** 2026-04-29
**Status:** Implemented
**References:** Design notes 0005 (power supply schematic), 0009 (initial floorplan), 0012 (previous placement); AMS1117 datasheet §7; IPC-7351B decoupling placement guidelines

---

## Summary

Nine power-supply components were relocated from their initial parking positions to their
final pre-routing positions, forming a coherent power cluster directly below-right of U1
(STM32F103C8T6 at (56, 67.25)). The AMS1117-3.3 LDO (U2) moved ~51 mm left — from
the far-right parking area to (65.5, 78.75) — anchoring the cluster at a central,
short-trace distance from both the USB input (J1) and the MCU VDD supply pins.

Fifteen components are unchanged from design note 0012.

---

## 1 — Component Position Changes

| Ref | Value | Footprint | Old (x, y) rot° | New (x, y) rot° | Role |
|-----|---|---|---|---|---|
| U2  | AMS1117-3.3  | SOT-223-3 | (116.29, 62.34) r=0 | **(65.5, 78.75) r=−90°**  | 3.3 V LDO regulator |
| C1  | 22 µF | 0805 | (124.53, 44.35) r=0 | **(63.55, 72.0) r=0°** | +3.3 V output bulk cap |
| C5  | 100 nF | 0402 | (122.65, 66.0) r=0 | **(60.25, 75.0) r=0°** | LDO output HF bypass |
| C2  | 22 µF | 0805 | (124.53, 47.36) r=0 | **(71.25, 79.2) r=90°** | VBUS input bulk cap |
| D1  | RED LED | LED_0603 | (124.35, 50.16) r=0 | **(73.75, 78.0) r=90°** | Power indicator |
| R1  | 1.5 kΩ | 0402 | (108.54, 61.72) r=0 | **(70.75, 73.24) r=90°**  | LED current limiter |
| C3  | 10 µF | 0603 | (118.62, 67.71) r=0 | **(50.475, 59.0) r=0°** | VDD/VDDA intermediate bulk |
| C6  | 100 nF | 0402 | (122.65, 71.0) r=0 | **(63.0, 65.52) r=90°** | VDD HF decoupling (MCU right side) |
| C7  | 100 nF | 0402 | (53.48, 60.0) r=0 | **(52.5, 60.75) r=0°** | VDD HF decoupling (MCU above) |

---

## 2 — Power Supply Cluster Layout

U2 (AMS1117-3.3, SOT-223-3) is now centred at **(65.5, 78.75)**, rotated −90° so its
**VO (output) pin** faces toward U1 (left/top) and its **VI (input) pin** faces toward
J1 USB connector (right).

```
X →    50    56    60    63    65    70    71
       |     |     |     |     |     |     |
  59  C3     .     .     .     .     .     .     ← VDD bulk (MCU supply path)
       .     .     .     .     .     .     .
  65   .     U1    .     .     .     .     .
       .     .     .    C6     .     .     .     ← HF bypass, MCU right side
  67   .     .     .     .     .    J1     .     ← USB Micro-B
       .     .     .     .     .     .     .
  72   .     .     .    C1     .     .     .     ← 22µF output bulk (VO side)
  73   .     .     .     .     .    R1     .     ← LED series resistor
  75   .     .    C5     .     .     .     .     ← 100nF output HF bypass
       .     .     .     .     .     .     .
  78   .     .     .     .     .    D1     .     ← Power LED
  79   .     .     .     .    U2    C2     .     ← LDO + 22µF input bulk (VI side)
```

### Distance summary

| Pair | Distance (approx.) | Significance |
|---|---|---|
| U2 → U1 | 14.4 mm | VDD distribution trace length |
| U2 VO → C1 | 7.0 mm | Output cap proximity (AMS1117 requires ≥10 µF within short trace) |
| U2 VO → C5 | 6.5 mm | HF bypass proximity |
| U2 VI → C2 | 5.8 mm | Input cap proximity |
| U2 VI → J1 | 5.2 mm | VBUS entry trace length |

---

## 3 — Placement Rationale

### 3.1 U2 (AMS1117-3.3 LDO)

The AMS1117-3.3 was moved from its right-side parking position to **(65.5, 78.75)**,
rotated −90°, placing it:

- **Below and to the right of U1**, so the VO (output) pin naturally faces up-left toward
  the MCU VDD network — minimising the power trace from regulator output to MCU supply pins.
- **Near J1** (USB Micro-B at (70.8, 65.875)), keeping the VBUS → VI trace short (~5 mm).
  This avoids routing 5 V across the board and reduces I²R drop before regulation.
- The −90° rotation orients the SOT-223 tab (GND) downward on B.Cu for thermal spreading
  and a direct ground connection via the bottom copper layer.

### 3.2 Output capacitors — C1 and C5

The AMS1117 datasheet specifies a minimum **10 µF output capacitor** for stability (ESR
0.1–1.0 Ω range). C1 (22 µF, 0805, MLCC) and C5 (100 nF, 0402) are placed on the VO
side of U2:

- **C1** at (63.55, 72.0) — 7 mm from U2, pads oriented for a direct VO → cap → GND path.
- **C5** at (60.25, 75.0) — smaller HF bypass, placed between C1 and U2 to cover
  frequencies above C1's self-resonance (~5 MHz for 22 µF 0805 MLCC).

Together they provide: 22 µF bulk stability + 100 nF HF decoupling on the +3.3 V rail.

### 3.3 Input capacitor — C2

**C2** (22 µF, 0805) is placed at (71.25, 79.2) on the VI (input/VBUS) side of U2.
The 22 µF on VI damps input voltage transients from the USB cable inductance and ensures
the LDO does not latch up on hot-plug. Rotated 90° to align pads with the vertical
VBUS trace from J1.

### 3.4 Power indicator — D1 and R1

**D1** (RED LED, 0603) at (73.75, 78.0) and **R1** (1.5 kΩ, 0402) at (70.75, 73.24) are
placed adjacent to the power supply cluster. Both rotated 90° to form a vertical
current path: +3.3V → R1 → D1 → GND. Placed near the board edge so the LED is
visible from outside the enclosure.

### 3.5 VDD intermediate bulk — C3

**C3** (10 µF, 0603) was repositioned to **(50.475, 59.0)** — above-left of U1 — to sit
at the entry point of the +3.3 V supply into the MCU decoupling network. It bridges the
LDO output capacitor bank (C1/C5, ~14 mm away) and the per-pin 100 nF decouplers
(C4/C7/C8), absorbing mid-frequency ripple (100 kHz–1 MHz) between the two stages.

### 3.6 VDD HF decouplers — C6 and C7 (minor adjustments)

- **C6** (100 nF) moved to (63.0, 65.52) r=90° — right side of U1, covering VDD pin 48
  (LQFP-48 right side). Short trace to MCU pad.
- **C7** (100 nF) minor nudge to (52.5, 60.75) — above U1, covering VDD pin 24.

---

## 4 — Final Power Supply Cluster — Complete Position Table

| Ref | Value | X (mm)  | Y (mm)  | Rot (°) | Notes |
|-----|---|---|---|---|---|
| U2  | AMS1117-3.3 | 65.500  | 78.750  | −90 | LDO, VO faces up-left toward U1 |
| C1  | 22 µF | 63.550  | 72.000  | 0 | VO output bulk |
| C5  | 100 nF | 60.250  | 75.000  | 0 | VO HF bypass |
| C2  | 22 µF | 71.250  | 79.200  |  90 | VI input bulk |
| R1  | 1.5 kΩ | 70.750  | 73.240  |  90 | LED current limiter |
| D1  | RED LED | 73.750  | 78.000  |  90 | Power indicator |
| C3  | 10 µF | 50.475  | 59.000  | 0 | VDD intermediate bulk |
| C6  | 100 nF | 63.000  | 65.520  |  90 | VDD HF decoupling, U1 right |
| C7  | 100 nF | 52.500  | 60.750  | 0 | VDD HF decoupling, U1 above |

---

## 5 — Unchanged Components (19)

C4, C8, C9, C10, C11, C12, C13, FB1, J1, J2, J3, J4, R2, R3, R4, R5, SW1, U1, Y1 —
retain positions from design notes 0009–0012.

---

## 6 — Next Steps

1. **Draw board outline** (Edge.Cuts) — all 27 components are now in final pre-routing
   positions. Left boundary ≈ X=38 (SW1), right boundary ≈ X=76 (D1/C2), top ≈ Y=52
   (J2/J3), bottom ≈ Y=82 (J4/C2).
2. **Route power rails** first: +3.3 V pour and GND pour on B.Cu. Connect U2 tab to GND.
3. **Route critical analog paths**: VDDA via FB1 → C9/C10; crystal OSC traces.
4. **Route USB differential pair** (J1 → R3 → U1 PA11/PA12).

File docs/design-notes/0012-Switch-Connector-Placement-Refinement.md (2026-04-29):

# 0012 — Switch, Connector, and Peripheral Circuit Placement Refinement

**Date:** 2026-04-29
**Status:** Implemented
**References:** Design notes 0002 (BOOT0/NRST), 0009 (initial floorplan), 0010 (USB/SWD), 0011 (PCM12 switch)

---

## Summary

Eight components were relocated from their initial parking positions to their final
pre-routing positions, grouped into three functional clusters around U1 (STM32F103C8T6):

| Cluster | Components moved |
|---|---|
| BOOT0 / switch circuit | SW1, R2 |
| Expansion connectors | J2, J3, J4 |
| MCU peripheral passives | R4, R5, C11 |

Twenty components remain at their positions from design notes 0009–0011 (U1, J1, Y1,
C1–C13, FB1, D1, R1, R3, U2).

---

## 1 — Component Position Changes

| Ref  | Value | Footprint | Old (x, y) rot° | New (x, y) rot° |
|---|---|---|---|---|
| SW1  | SW_SPDT | SW_SPDT_PCM12 (SMD) | (99.60, 46.46) r=0  | **(40.43, 56.65) r=−90°** |
| R2 | 10 kΩ BOOT0 | R_0402 | (108.54, 63.71) r=0 | **(47.24, 57.25) r=0** |
| J2 | Conn_01x04_Pin | PinHeader_1x04_P1.00mm_SMD | (114.14, 55.11) r=0 | **(59.375, 54.0) r=0** |
| J3 | Conn_01x04_Pin | PinHeader_1x04_P1.00mm_SMD | (62.875, 58.0) r=0  | **(52.125, 54.0) r=0** |
| J4 | Conn_01x04_Pin | PinHeader_1x04_P1.00mm_SMD | (125.24, 55.11) r=0 | **(52.625, 81.0) r=90°**  |
| R4 | 1.5 kΩ I2C SCL | R_0402 | (107.99, 70.74) r=0 | **(56.76, 80.25) r=0** |
| R5 | 1.5 kΩ I2C SDA | R_0402 | (39.70, 68.32) r=0  | **(46.74, 79.0) r=0** |
| C11  | 100 nF NRST | C_0402 | (125.52, 71.0) r=0  | **(54.0, 74.0) r=0** |

---

## 2 — Placement Rationale

### 2.1 BOOT0 Circuit — SW1 and R2

**SW1** (CK PCM12 SMD slide switch) relocated from the top-right parking area to
**(40.43, 56.65) r=−90°**, placing it to the left of the MCU body.

- The PCM12 is rotated −90° so its slide travel aligns with the board edge, making it
  accessible after PCB assembly.
- New position is ~15 mm left of U1 centre, keeping the BOOT0 trace (SW1 → BOOT0 pin 44
  via R2) short and avoiding the USB / crystal routing areas.
- **R2** (10 kΩ BOOT0 series resistor) follows SW1 to **(47.24, 57.25)**, placed inline
  between SW1 and U1 pin 44 (BOOT0, left side of LQFP-48).

```
SW1 (40.43, 56.65) ──R2 (47.24, 57.25)──► U1 pin 44 (BOOT0)
       ↑
  PCM12, slide
  accessible from
  board left edge
```

### 2.2 Expansion Connectors — J2, J3, J4

All three 4-pin 1.00 mm SMD pin headers were relocated from the right-side parking
cluster to positions flanking U1:

| Ref | New position | Assignment |
|-----|---|---|
| J3  | (52.125, 54.0)  | SWD/SWO debug header — above-left of U1, ~13 mm from MCU centre |
| J2  | (59.375, 54.0)  | Expansion connector — above-right of U1 |
| J4  | (52.625, 81.0) r=90° | Expansion connector — below U1, rotated 90° to align pads vertically |

J2 and J3 are placed in a row at Y=54, ~5 mm above U1 (centre Y=67.25), providing a
horizontal connector strip above the MCU. Pitch between J3 and J2 is 7.25 mm, leaving
routing channels between them. J4 is placed below U1, rotated 90° to route signals
downward off the MCU's lower pads.

### 2.3 MCU Peripheral Passives — R4, R5, C11

**R4** (1.5 kΩ I2C2 SCL pull-up) and **R5** (1.5 kΩ I2C2 SDA pull-up) moved from their
scattered parking positions to the area immediately below U1:

- **R4** at (56.76, 80.25) — below U1, aligned with PB10/PB11 (I2C2_SCL/SDA, pins 29–30
  on the bottom of the LQFP-48).
- **R5** at (46.74, 79.0) — adjacent to R4, both at Y ≈ 79–80, giving a short pull-up
  trace to the I2C bus pads.

**C11** (100 nF NRST filter capacitor) moved from its right-side parking position to
**(54.0, 74.0)**, placing it near U1 pin 7 (NRST) on the left side of the LQFP-48.
This minimises the stub length on the NRST net, which is important for correct MCU reset
filtering (RC time constant with R_internal and C11 ≈ 100 ns at 100 nF per design note 0002).

---

## 3 — Updated Cluster Layout (Approximate, mm)

```
X →   40       47       52  54  56  59       70
      |        |        |   |   |   |        |
  54  .        .        J3  .   .   J2       .
      .        .        .   .   .   .        .
  57  SW1      R2       .   .   .   .        .
      .        .        .   .   .   .        .
  63  .        .        .   .   .   .        .
      .        .        .   .   .   .        J1
  67  .        .        .   U1(56,67.25)     .
      .        .        .   .   .   .        .
  74  .        .        C11 .   .   .        .
      .        .        .   .   .   .        .
  79  .        .        R5  .   .   .        .
  80  .        .        .   .   R4  .        .
  81  .        .        J4  .   .   .        .
```

---

## 4 — Unchanged Components (20)

U1, J1, Y1, C1, C2, C3, C4, C5, C6, C7, C8, C9, C10, C12, C13, D1, FB1, R1, R3, U2 —
all retain positions from design notes 0009–0011.

---

## 5 — Next Steps

1. **Draw board outline** (Edge.Cuts) — all components are now in final pre-routing
   positions; the left-side extent is defined by SW1 at X≈40, right side by U2/D1 at
   X≈125, top by J1 USB connector.
2. **Run DRC courtyard check** — verify PCM12 (SW1) and J4 (rotated 90°) clear adjacent
   components.
3. **Begin copper routing** — recommended order:
   - Power (GND / +3.3 V pours on B.Cu)
   - USB differential pair (J1 → R3 → U1 PA11/PA12)
   - SWD/SWO (J3 → U1 PA13/PA14/PB3)
   - BOOT0 (SW1 → R2 → U1 pin 44)
   - NRST (C11 → U1 pin 7)
   - I2C (R4/R5 → U1 PB10/PB11)

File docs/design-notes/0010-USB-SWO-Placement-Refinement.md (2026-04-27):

# 0010 — USB and SWO/SWD Circuit Component Placement Refinement

**Date:** 2026-04-27
**Status:** Implemented
**References:** Design notes 0004 (USB), 0009 (initial placement); USB 2.0 Full-Speed spec §7.1.8; ST UM1724 (STM32 Nucleo SWD layout)

---

## Summary

Four components from the initial floorplan (design note 0009) were relocated to their
final pre-routing positions to support two signal-integrity-sensitive circuits:

1. **USB Full-Speed** — J1 (USB Micro-B) + R3 (D+ pull-up) moved adjacent to U1 with
   matched differential-pair trace length in mind.
2. **SWD/SWO debug header** — J3 (4-pin 1.00 mm SMD header) moved above U1 to sit near
   the MCU's SWD and SWO pins.

No copper routes or vias were added in this commit; all changes are footprint position
and rotation updates only.

---

## 1 — USB Circuit Placement

### Component moves

| Ref | Value | Previous position (mm) | New position (mm) | Rotation change |
|-----|---|---|---|---|
| J1  | USB Micro-B | (116.83, 46.71) rot=0° | **(70.80, 65.875) rot=90°** | +90° |
| R3  | 1.5 kΩ D+ | (108.54, 65.70) rot=0° | **(64.75, 65.49) rot=−90°** | −90° |

### Rationale

The USB Micro-B connector (**J1**) and the D+ pull-up resistor (**R3**) were originally
placed in the right-hand power cluster as temporary parking positions. For USB Full-Speed
(12 Mbit/s) differential signalling, the key layout rules are:

- **D+ and D− traces must be length-matched** (ΔL < 0.5 mm for FS per USB 2.0 §7.1.8).
- **Total stub length from connector to MCU should be minimised** (< 25 mm recommended).
- **R3 (series pull-up)** must sit on the D+ net between J1 pad 3 and MCU pin PA12
  (pin 33, LQFP-48 right side) to force USB FS device enumeration.

New position analysis:

```
Board X-axis (mm): 56      64.75  70.8
                   |          |    |
                  U1        R3    J1
                  (MCU)     (D+) (USB)
                 PA12 pin→──R3───J1 pad 3
                 PA11 pin→───────J1 pad 2
```

- **J1** rotated 90° so its five signal pads (VBUS, D−, D+, ID, GND) face vertically toward
  the MCU. The connector opening faces the bottom board edge (−Y direction), providing
  panel cut-out access from the board edge without running the cable across the board.
- With J1 at X=70.8 and U1 at X=56, the D+/D− pads of J1 are approximately **14.8 mm**
  from the corresponding MCU pads (PA11/PA12 on the right side of LQFP-48). This is well
  within the < 25 mm guideline.
- **R3** at X=64.75 sits between J1 and U1, placing it on the D+ line with minimal stub.
  Rotated −90° so its pads align with the vertical D+ trace.

---

## 2 — SWD/SWO Debug Header Placement

### Component move

| Ref | Value | Previous position (mm) | New position (mm) | Rotation change |
|-----|---|---|---|---|
| J3  | Conn_01x04_Pin | (119.69, 55.11) rot=0° | **(62.875, 58.0) rot=0°** | none |

### SWD/SWO pin assignment on STM32F103C8T6

| MCU pin | Signal | Net | LQFP-48 side |
|---|---|---|---|
| 34 — PA13 | SWDIO | SWD_DATA | Right |
| 37 — PA14 | SWDCLK  | SWD_CLK | Right |
| 39 — PB3  | SWO | SWO_TDO | Right (lower) |
| — (VCC/GND) | — | +3.3V / GND | — |

### Rationale

J3 is used as the 4-pin SWD + SWO debug connector (VCC, GND, SWDIO, SWDCLK; SWO via
PB3 on a separate net). It was relocated from the right-side connector bank at X=119 to
**(62.875, 58)**, which places it:

- Directly **above U1** (MCU centre at (56, 67.25), J3 is 9.25 mm above).
- Within ~6–10 mm of the MCU's PA13 (SWDIO) and PA14 (SWDCLK) pads on the right side
  of the LQFP-48 package.

This keeps the SWD traces short and avoids routing debug signals across the full board.
A short SWD stub reduces susceptibility to capacitive loading on the SWDCLK line, which
is important at the 4 MHz default SWD clock.

```
      J3 (62.875, 58)
       ↓  ↓  ↓  ↓
      [SWD/SWO header]
             ↑
           ~9 mm
             ↑
      U1 (56, 67.25)  ←─ PA13/PA14 pads on right side of LQFP-48
```

---

## 3 — Minor R4 Adjustment

| Ref | Value | Previous position (mm) | New position (mm)  |
|-----|---|---|---|
| R4  | 1.5 kΩ I2C SCL| (108.54, 67.69) rot=0° | (107.99, 70.74) rot=0° |

R4 (I2C2 SCL pull-up) received a minor position nudge (~3 mm south) to improve clearance
with adjacent components in the right-hand resistor column. Function is unchanged.

---

## 4 — Updated Position Summary (Affected Components)

| Ref | Value | X (mm)  | Y (mm)  | Rot (°) | Layer | Footprint |
|-----|---|---|---|---|---|---|
| J1  | USB Micro-B | 70.80 | 65.875  |  90 | F.Cu  | USB_Micro-B_Wuerth_629105150521 |
| J3  | SWD/SWO hdr | 62.875  | 58.00 | 0 | F.Cu  | PinHeader_1x04_P1.00mm_Vertical_SMD |
| R3  | 1.5 kΩ D+ | 64.75 | 65.49 | −90 | F.Cu  | R_0402_1005Metric |
| R4  | 1.5 kΩ SCL  | 107.99  | 70.74 | 0 | F.Cu  | R_0402_1005Metric |

---

## 5 — Next Steps

1. **Route USB differential pair** (D+ / D−): route J1 pads 2–3 to MCU PA11/PA12 as a
   matched-length pair; insert R3 in-line on D+. Aim for trace width ≈ 0.2 mm and
   spacing ≈ 0.2 mm (50 Ω single-ended, ≈ 90 Ω differential; FR4 2-layer geometry).
2. **Route SWD/SWO signals** (J3 → PA13, PA14, PB3): straightforward low-speed traces;
   keep SWO (PB3) length < 50 mm to avoid reflections at higher SWO clock rates.
3. **Draw board outline** (Edge.Cuts) now that the USB connector and debug header are in
   their final positions — J1 rotation defines the connector edge cut direction.

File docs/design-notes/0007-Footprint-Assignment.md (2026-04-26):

# 0007 — Footprint Assignment (STM32F103C8T6)

**Date:** 2026-04-26
**Status:** Implemented
**References:** KiCad footprint library (built-in)

---

## Summary

All schematic symbols that previously had an empty `Footprint` field were assigned PCB
footprints using **KiCad Tools → Assign Footprints**. This is the first full footprint
pass; U1 (STM32F103C8T6) and U2 (AMS1117-3.3) were already assigned in earlier commits
and are unchanged here.

A total of **26** footprint fields changed from `""` to a named KiCad library footprint.
No values, reference designators, or net connections were modified.

---

## Full Footprint Assignment Table

| Ref  | Value | Footprint | Package / Notes |
|---|---|---|---|
| **Connectors** |
| J1 | USB Micro-B | `Connector_USB:USB_Micro-B_Wuerth_629105150521` | Würth 629105150521, through-hole tabs |
| J2 | Conn_01x04 | `Connector_PinHeader_1.00mm:PinHeader_1x04_P1.00mm_Vertical_SMD_Pin1Right` | 1.00 mm pitch SMD, pin 1 right |
| J3 | Conn_01x04 | `Connector_PinHeader_1.00mm:PinHeader_1x04_P1.00mm_Vertical_SMD_Pin1Right` | 1.00 mm pitch SMD, pin 1 right |
| J4 | Conn_01x04 | `Connector_PinHeader_1.00mm:PinHeader_1x04_P1.00mm_Vertical_SMD_Pin1Right` | 1.00 mm pitch SMD, pin 1 right |
| **Passives — Capacitors** |
| C1 | 22 µF | `Capacitor_SMD:C_0805_2012Metric` | 0805 — +3.3V output bulk cap (U2 VO) |
| C2 | 22 µF | `Capacitor_SMD:C_0805_2012Metric` | 0805 — VBUS input bulk cap (U2 VI) |
| C3 | (VDD/VDDA bulk) | `Capacitor_SMD:C_0603_1608Metric` | 0603 — larger bypass (e.g. 1 µF); leftmost MCU supply cap |
| C4 | 100 nF | `Capacitor_SMD:C_0402_1005Metric` | 0402 — VDD decoupling |
| C5 | 100 nF | `Capacitor_SMD:C_0402_1005Metric` | 0402 — VDD decoupling |
| C6 | 100 nF | `Capacitor_SMD:C_0402_1005Metric` | 0402 — VDD decoupling |
| C7 | 100 nF | `Capacitor_SMD:C_0402_1005Metric` | 0402 — VDD decoupling |
| C8 | 100 nF | `Capacitor_SMD:C_0402_1005Metric` | 0402 — VDD decoupling |
| C9 | 100 nF | `Capacitor_SMD:C_0402_1005Metric` | 0402 — VDD decoupling |
| C10  | 100 nF | `Capacitor_SMD:C_0402_1005Metric` | 0402 — VDD decoupling |
| C11  | 100 nF | `Capacitor_SMD:C_0402_1005Metric` | 0402 — NRST filter cap |
| C12  | 22 pF | `Capacitor_SMD:C_0402_1005Metric` | 0402 — HSE crystal load cap |
| C13  | 22 pF | `Capacitor_SMD:C_0402_1005Metric` | 0402 — HSE crystal load cap |
| **Passives — Resistors** |
| R1 | 1.5 kΩ | `Resistor_SMD:R_0402_1005Metric` | 0402 — Power LED current limiter |
| R2 | 10 kΩ | `Resistor_SMD:R_0402_1005Metric` | 0402 — BOOT0 series resistor |
| R3 | 1.5 kΩ | `Resistor_SMD:R_0402_1005Metric` | 0402 — USB D+ pull-up |
| R4 | 1.5 kΩ | `Resistor_SMD:R_0402_1005Metric` | 0402 — I2C2 SCL pull-up |
| R5 | 1.5 kΩ | `Resistor_SMD:R_0402_1005Metric` | 0402 — I2C2 SDA pull-up |
| **Active / Semiconductor** |
| D1 | RED | `LED_SMD:LED_0603_1608Metric` | 0603 LED — power indicator |
| **Electromechanical** |
| SW1  | BOOT0 switch | `Button_Switch_THT:SW_E-Switch_EG1224_SPDT_Angled` | THT, SPDT angled slide switch |
| Y1 | 16 MHz crystal | `Crystal:Crystal_SMD_3225-4Pin_3.2x2.5mm` | 3.2 × 2.5 mm 4-pad SMD |
| FB1  | Ferrite bead | `Inductor_SMD:L_0603_1608Metric` | 0603 (standard ferrite bead SMD size) |

**Already assigned (unchanged):**

| Ref  | Footprint |
|---|---|
| U1 | `Package_QFP:LQFP-48_7x7mm_P0.5mm` |
| U2 | `Package_TO_SOT_SMD:SOT-223-3_TabPin2` |

---

## Footprint Selection Rationale

### Capacitors

| Case | Footprint | Reason |
|---|---|---|
| C1, C2 — 22 µF bulk | 0805 | 22 µF in X5R/X7R ceramic is readily available in 0805; 0402/0603 22 µF parts have very low voltage rating or poor capacitance derating |
| C3 — larger bypass | 0603 | Assigned a 0603 pad to accommodate a 1 µF (or higher) value bulk capacitor alongside the 100 nF 0402 decouplers; 0603 allows 1 µF X7R with good voltage margin |
| C4–C11 — 100 nF | 0402 | 100 nF 0402 is the industry standard for high-frequency VDD decoupling; small footprint enables placement directly under MCU body |
| C12, C13 — 22 pF crystal load | 0402 | 22 pF NP0/C0G in 0402 provides the required low-loss, temperature-stable capacitance for the HSE oscillator |

### Connectors

J2, J3, J4 use **1.00 mm pitch SMD** pin headers (`PinHeader_1x04_P1.00mm_Vertical_SMD_Pin1Right`).
This is a compact SMD footprint suitable for low-profile board-to-board or board-to-cable
connections.

> **Note:** If through-hole 2.54 mm pitch (standard 0.1") headers are preferred for hand
> soldering or breadboard use, replace with
> `Connector_PinHeader_2.54mm:PinHeader_1x04_P2.54mm_Vertical` at layout time.

### SW1 — BOOT0 Switch

`Button_Switch_THT:SW_E-Switch_EG1224_SPDT_Angled` is a through-hole SPDT angled slide
switch. THT was chosen for mechanical robustness — the BOOT0 switch is manipulated by
hand during firmware programming and benefits from stronger solder joints than SMD.

### Y1 — 16 MHz Crystal

`Crystal:Crystal_SMD_3225-4Pin_3.2x2.5mm` matches the 4-pad 3225 package standard for
the crystal specified in design note 0003. Pins 2 and 4 are GND (chassis) pads;
the symbol `Device:Crystal_GND24` reflects this.

### FB1 — Ferrite Bead

`Inductor_SMD:L_0603_1608Metric` is the standard 0603 pad used for ferrite beads in the
KiCad library. All common ferrite bead manufacturers (Murata BLM series, TDK MMZ series)
supply 0603-footprint parts for VDDA filtering.

---

## Checklist

| Item | Functional impact | BOM impact |
|---|:---:|:---:|
| 26 footprints assigned (was `""`) | None | No (values unchanged) |
| U1, U2 footprints unchanged | None | No |

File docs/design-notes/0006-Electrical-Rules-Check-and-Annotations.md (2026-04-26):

# 0006 — Electrical Rules Check and Annotations (STM32F103C8T6)

**Date:** 2026-04-26
**Status:** Implemented
**References:** KiCad ERC documentation

---

## Summary of Changes

This revision makes no functional or component changes. It resolves all KiCad Electrical
Rules Check (ERC) violations, adds schematic title block metadata, adds in-schematic
annotation text, repositions several components within the power supply area for improved
readability, and re-annotates all capacitors and resistors in positional (left-to-right,
top-to-bottom) order.

---

## 1 — PWR_FLAG: Resolving ERC "Power Pin Not Driven" Errors

### Problem

KiCad's ERC checks that every power net has a **driver** — a pin with type `power_out`.
Passive power symbols (`power:+3.3V`, `power:VBUS`, `power:GND`, etc.) have a pin of
type `power_in`, not `power_out`. When a power net is supplied by an external source
(e.g. via a connector or an off-sheet regulator) rather than an on-sheet `power_out` pin,
KiCad cannot resolve the driver and reports:

```
ERC error: Pin not connected / Power pin not driven
```

### Solution: PWR_FLAG (#FLG01)

A `power:PWR_FLAG` symbol was placed on the **+3.3VA** (VDDA) net at position (215.9, 36.83).

```
+3.3VA ──┬── [VDDA filter network] ── MCU VDDA
         │
        #FLG01 (PWR_FLAG)
```

`PWR_FLAG` is a zero-footprint, no-BOM symbol whose sole purpose is to expose a
`power_out` pin onto the net, satisfying the ERC driver rule. It has no electrical
effect in the circuit — it is an annotation artefact only.

| Reference | lib_id | Net | Purpose |
|---|---|---|---|
| #FLG01 | power:PWR_FLAG  | +3.3VA | Suppresses "power pin not driven" ERC on VDDA net |

> **Why VDDA?** The VDDA net is derived from +3.3V through an LC filter (see note 0001).
> Because its driver (the +3.3V regulator VO pin) is on a different net name, KiCad
> cannot automatically trace the supply chain. PWR_FLAG makes the VDDA net self-consistent
> from the ERC perspective.

---

## 2 — Title Block Metadata

The schematic title block was populated for the first time:

| Field | Value |
|---|---|
| Title | UDEMY STM32 Demo |
| Date | 2026-04-26 |
| Revision | 0.0.1 |

This information appears in the sheet border/title block printed on schematic exports
(PDF, SVG). It provides version traceability and identifies the project.

---

## 3 — Schematic Annotation Text

Eight in-schematic text labels were added to document design intent directly on the
schematic sheet. These are non-electrical drawing annotations (no reference, no BOM
entry, no ERC participation).

| Text | Location (approx.) | Purpose |
|---|---|---|
| `Power supply` | Power supply area  | Section heading |
| `VBUS from USB connector. Normally it is +5V. Minimum 22uF inp./outp caps`| Near U2/C12/C13 | Reminds the designer of input/output bulk cap requirement |
| `Microcontroller and USB` | MCU area heading | Section heading |
| `1x 100nF capacitor per VDD pin` | Decoupling area | States the decoupling rule (see note 0001) |
| `VDDA Filtering` | VDDA filter area | Section heading for the VDDA LC filter |
| `CL=2*(CLO-Cs)=2*(10-5)pF=10pF` | Crystal area | Documents the crystal load capacitor calculation (see note 0003) |
| `USB Application Note AN 4879` | USB area | Cross-reference to the ST USB hardware guidelines |
| `Pin-out using STM32CubeIDE` | Connector area | Documents that MCU pin assignments were configured in CubeIDE |

The crystal load capacitance annotation formalises the calculation already implicit in
note 0003:

$$C_L = 2 \times (C_{L,osc} - C_s) = 2 \times (10 - 5)\,\text{pF} = 10\,\text{pF}$$

where $C_{L,osc}$ is the crystal's specified load capacitance and $C_s$ is the estimated
PCB stray capacitance per pin.

---

## 4 — Component Repositioning (Power Supply Area)

Several components in the power supply and power LED circuits were shifted to improve
schematic readability and wire routing cleanliness. No values, footprints, or net
connections changed — only (x, y) placement coordinates.

| Reference | Old position (mm) | New position (mm) | Description |
|---|---|---|---|
| VBUS #PWR | (25.4, 41.91) | (30.48, 40.64) | VBUS power symbol |
| C13 | (25.4, 53.34) | (30.48, 53.34) | +3.3V output bulk cap |
| +3.3V #PWR (C13 side) | (62.23, 41.91) | (55.88, 40.64) | +3.3V power symbol |
| C12 | (62.23, 52.07) | (55.88, 52.07) | VBUS input bulk cap |
| D1 | (86.36, 48.26) | (66.04, 48.26) | Power LED |
| R3 | (97.79, 53.34) | (77.47, 53.34) | LED current-limiting resistor |
| PWR_LED_K label | (92.71, 48.26) | (72.39, 48.26)  | Cathode net label |
| GND (U2 output) | (45.72, 76.2) | (45.72, 64.77) | GND symbol on regulator output side |
| +3.3VA #PWR | (200.66, 26.67) | (200.66, 30.48) | VDDA power symbol |

The LED chain (R3 → D1) was shifted approximately 20 mm to the left, shortening the
horizontal span of the power supply section. Wire segments and junction points were
updated accordingly throughout.

---

## 5 — ngspice Settings Added to Project File

The `.kicad_pro` project file gained an `ngspice` settings block:

```json
"ngspice": {
  "fix_include_paths": true,
  "meta": { "version": 0 },
  "model_mode": 4,
  "workbook_filename": ""
}
```

This was added automatically by KiCad when the schematic editor was opened with the
ngspice simulation plugin active. It has no effect on the PCB or BOM — it is a UI
preference block only.

---

## 6 — Component Re-annotation (Positional Ordering)

KiCad's **Tools → Re-Annotate Schematic** was run with positional (left-to-right,
top-to-bottom) sorting. This assigns reference numbers in the order components appear
on the sheet, making it easier to cross-reference the schematic with a physical board.

No values, footprints, or net connections changed — only the reference designators.

### Capacitor Re-annotation

| Old Ref | New Ref | Value  | Circuit / Function | Design note |
|---|---|---|---|---|
| C1 | C7 | 100 nF | VDD decoupling (MCU) | 0001 |
| C2 | C6 | 100 nF | VDD decoupling (MCU) | 0001 |
| C3 | C5 | 100 nF | VDD decoupling (MCU) | 0001 |
| C5 | C3 | 100 nF | VDD decoupling (MCU) | 0001 |
| C6 | C8 | 100 nF | VDD decoupling (MCU) | 0001 |
| C7 | C9 | 100 nF | VDD decoupling (MCU) | 0001 |
| C8 | C10 | 100 nF | VDD decoupling (MCU) | 0001 |
| C9 | C11 | 100 nF | NRST filter capacitor | 0002 |
| C10 | C13 | 22 pF  | Crystal load capacitor (HSE, Y1 side) | 0003 |
| C11 | C12 | 22 pF  | Crystal load capacitor (MCU, Y1 side) | 0003 |
| C12 | C2 | 22 µF  | VBUS input bulk cap (U2 VI side) | 0005 |
| C13 | C1 | 22 µF  | +3.3V output bulk cap (U2 VO side) | 0005 |

### Resistor Re-annotation

| Old Ref | New Ref | Value  | Circuit / Function | Design note |
|---|---|---|---|---|
| R1 | R2 | 10 kΩ  | BOOT0 series resistor | 0002 |
| R2 | R3 | 1.5 kΩ | USB D+ pull-up | 0004 |
| R3 | R1 | 1.5 kΩ | Power LED current-limiting resistor | 0005 |

> **Note for cross-referencing earlier design notes:** Design notes 0001–0005 use the
> old reference designators. The table above is the authoritative mapping. All subsequent
> notes use the new (post-re-annotation) references.

---

## Checklist: Changes with No Functional Impact

| Change type | Functional impact | BOM impact | PCB footprint impact |
|---|:---:|:---:|:---:|
| PWR_FLAG (#FLG01) placed | None | No (DNP / no footprint) | None |
| Title block filled | None | No | None |
| Schematic text annotations | None | No | None |
| Component repositioning | None | No | None (only schematic coords) |
| Wire/junction rerouting | None | No | None |
| ngspice project settings | None | No | None |
| Reference re-annotation | None | No (same components) | None |

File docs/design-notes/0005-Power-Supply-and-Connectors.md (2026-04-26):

# 0005 — Power Supply and Connectors (STM32F103C8T6)

**Date:** 2026-04-26
**Status:** Implemented
**References:**
- AMS1117 Datasheet — `docs/datasheets/AMS1117.pdf`
- `docs/datasheets/AMS1117-3-3 Linear-Voltage-Regulator.png`

---

## Bill of Materials (machine-readable)

| Ref | Value | lib_id | Footprint | Datasheet |
|-----|---|---|---|---|
| U2  | AMS1117-3.3  | Regulator_Linear:AMS1117-3.3 | Package_TO_SOT_SMD:SOT-223-3_TabPin2 | http://www.advanced-monolithic.com/pdf/ds1117.pdf |
| C12 | 22u | Device:C | Capacitor_SMD:C_0402_1005Metric | ~ |
| C13 | 22u | Device:C | Capacitor_SMD:C_0402_1005Metric | ~ |
| D1  | RED | Device:LED | LED_SMD:LED_0402_1005Metric | ~ |
| R3  | 1k5 | Device:R | Resistor_SMD:R_0402_1005Metric | ~ |
| R4  | 1k5 | Device:R | Resistor_SMD:R_0402_1005Metric | ~ |
| R5  | 1k5 | Device:R | Resistor_SMD:R_0402_1005Metric | ~ |
| J2  | Conn_01x04 | Connector:Conn_01x04_Pin | Connector_PinHeader_2.54mm:PinHeader_1x04_P2.54mm_Vertical | ~ |
| J3  | Conn_01x04 | Connector:Conn_01x04_Pin | Connector_PinHeader_2.54mm:PinHeader_1x04_P2.54mm_Vertical | ~ |
| J4  | Conn_01x04 | Connector:Conn_01x04_Pin | Connector_PinHeader_2.54mm:PinHeader_1x04_P2.54mm_Vertical | ~ |

---

## 1 — Voltage Regulator: U2 (AMS1117-3.3)

### Context

The STM32F103C8T6 and all on-board peripherals require a regulated 3.3 V supply. The
board is powered via the USB Micro-B connector (J1, added in 0004), which provides 5 V
on the VBUS net. The AMS1117-3.3 is a 1 A, 1.117 V low-dropout linear regulator with a
fixed 3.3 V output, in SOT-223-3 (TabPin2) package.

### Pinout

| Pin | Name | Function |
|-----|---|---|
| 3 | VI | Input — connected to VBUS (5 V) |
| 2 | VO | Output — connected to +3.3V rail |
| 1 | GND  | Ground |
| Tab | VO | Exposed pad (tab), internally connected to VO — tied to +3.3V net and used for thermal dissipation |

### Circuit

```
VBUS (5 V) ──┬── C12 (22µF) ── GND     ← Input bulk cap
             │
            U2 VI (pin 3)
            U2 GND (pin 1) ── GND
            U2 VO (pin 2) ──┬── +3.3V  ← Output to MCU and peripherals
                            │
                           C13 (22µF) ── GND   ← Output bulk cap
```

### Decoupling Capacitors

| Ref | Value | Location | Purpose |
|-----|---|---|---|
| C12 | 22 µF | VBUS (input) | Input bulk cap — stabilises VBUS against cable inductance and host impedance |
| C13 | 22 µF | +3.3V (output) | Output bulk cap — LDO stability and load transient response |

The AMS1117 datasheet requires a minimum output capacitor of 10 µF for stability. 22 µF
provides margin and handles load steps from MCU peripheral startup (e.g. USB enumeration,
oscillator startup). The input capacitor C12 is recommended by the datasheet to prevent
oscillation when the input source has significant series inductance (e.g. USB cable).

### Power Budget

| Consumer | Typical current |
|---|---|
| STM32F103C8T6 | ~25 mA at 72 MHz |
| USB D+ pull-up | < 1 mA |
| Power LED (D1) | ~1 mA |
| Peripherals | < 10 mA |
| **Total** | **< 40 mA** |

The AMS1117-3.3 is rated for 1 A output. At 40 mA load, the power dissipation in SOT-223
is well within limits:

$$P_{diss} = (V_{IN} - V_{OUT}) \times I_{LOAD} = (5 - 3.3) \times 0.04 \approx 68 \text{ mW}$$

The SOT-223 package has a typical thermal resistance of ~$170\,°C/W$ (junction-to-ambient),
giving a temperature rise of ~12 °C — no heatsinking required.

---

## 2 — Power Indicator LED: D1 + R3

### Circuit

```
+3.3V ── R3 (1.5 kΩ) ──[A D1 K]── PWR_LED_K net ── GND
```

D1 is a red LED used as a power-on indicator. R3 limits the LED current. The net label
`PWR_LED_K` connects D1's cathode to GND.

### Current Calculation

Using a typical red LED forward voltage of $V_F \approx 1.8\,V$:

$$I_{LED} = \frac{V_{CC} - V_F}{R3} = \frac{3.3 - 1.8}{1500} = 1\,\text{mA}$$

1 mA provides a clearly visible indication at low power consumption. The 1.5 kΩ value
was chosen to match other resistors already on the board (USB D+ pull-up R2). For a
brighter LED, R3 can be reduced to 470 Ω (~3.2 mA) without exceeding the typical
20 mA maximum rating of a 0402 LED.

---

## 3 — Peripheral Breakout Connectors: J2, J3, J4

Three 4-pin 2.54 mm pitch pin headers are added to expose MCU peripheral signals
for external connections (sensors, debug adapters, etc.).

### J2 — Debug / Peripheral Header

J2 exposes signals in the USB and SWD area of the MCU, including:

| J2 pin | Signal | MCU pin | Description |
|---|---|---|---|
| 1 | USB_D− | PA11 (21)| USB differential data minus |
| 2 | USB_D+ | PA12 (22)| USB differential data plus |
| 3 | SDIO | PA13 (34)| SWDIO — SWD data line |
| 4 | SWCLK | PA14 (37)| SWDCLK — SWD clock line |

> "SDIO" is used on the schematic as the net label for SWDIO (PA13). This is a labelling
> choice — the signal is SWD Data I/O, not the SDIO peripheral.

### J3 — USART1 Connector

J3 provides access to the USART1 interface and power rails:

| J3 pin | Signal | MCU pin | Description |
|---|---|---|---|
| 1 | +3.3V | — | 3.3 V power output |
| 2 | USART1_TX | PA9 (30)| USART1 transmit |
| 3 | USART1_RX | PA10 (31)| USART1 receive |
| 4 | GND | — | Ground |

### J4 — I2C2 Connector

J4 provides access to the I2C2 interface with on-board pull-up resistors R4 and R5:

| J4 pin | Signal | MCU pin  | Description |
|---|---|---|---|
| 1 | +3.3V | — | 3.3 V power output |
| 2 | I2C2_SCL | PB10 (21)| I2C2 clock line |
| 3 | I2C2_SDA | PB11 (22)| I2C2 data line |
| 4 | GND | — | Ground |

---

## 4 — I2C Pull-up Resistors: R4, R5

R4 and R5 are 1.5 kΩ pull-up resistors for I2C2_SCL and I2C2_SDA respectively,
connected between each signal line and +3.3V.

I2C requires open-drain lines pulled to VCC. The pull-up resistor value determines
the maximum bus speed and rise time:

$$t_r \approx 0.8473 \times R_p \times C_{bus}$$

For 1.5 kΩ and an estimated bus capacitance of 50 pF (short PCB traces + device inputs):

$$t_r \approx 0.8473 \times 1500 \times 50 \times 10^{-12} \approx 63\,\text{ns}$$

| Mode | Max rise time | 1.5 kΩ result | Compatible? |
|---|---|---|---|
| Standard (100 kHz) | 1000 ns | 63 ns | Yes |
| Fast (400 kHz) | 300 ns  | 63 ns | Yes |
| Fast Plus (1 MHz)  | 120 ns  | 63 ns | Yes |

1.5 kΩ is suitable for Fast Mode (400 kHz) operation on a compact PCB. It also matches
the other 1.5 kΩ resistors on the board (R2 — USB D+ pull-up), simplifying the BOM.

---

## Placement Notes

- **U2**: Place close to J1 (USB connector) to minimise the VBUS trace length. C12 goes
  between J1 VBUS pin and U2 VI, as close to U2 as possible. C13 goes on the +3.3V side
  of U2 VO as close as possible to the output pin.
- **D1 + R3**: Place near the edge of the board for visibility. Route the anode of D1 to
  the +3.3V rail via R3.
- **J2, J3, J4**: Pin headers should be accessible on the board edge or perimeter, oriented
  consistently (pin 1 marked with a square pad). J3 and J4 are placed near each other to
  allow stacked cables or a ribbon connection to external peripherals.
- **R4, R5**: Place directly between the +3.3V rail via and the I2C2 signal traces leading
  to J4, as close to J4 as possible to minimise stub length on the pull-up path.

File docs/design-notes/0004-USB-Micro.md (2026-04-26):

# 0004 — USB Micro-B Interface (STM32F103C8T6)

**Date:** 2026-04-26
**Status:** Implemented
**References:**
- ST AN4879 — *Introduction to USB hardware and PCB guidelines using STM32 MCUs*
- `docs/datasheets/an4879-introduction-to-usb-hardware-and-pcb-guidelines-using-stm32-mcus-stmicroelectronics.pdf`

---

## Bill of Materials (machine-readable)

| Ref | Value | lib_id | Footprint | Datasheet |
|-----|---|---|---|---|
| J1  | USB_B_Micro  | Connector:USB_B_Micro | Connector_USB:USB_Micro-B_Molex_47589-0001 | ~ |
| R2  | 1k5 | Device:R | Resistor_SMD:R_0402_1005Metric | ~ |

---

## Context

The STM32F103C8T6 contains a built-in USB 2.0 Full Speed (FS) device controller
operating at 12 Mbps. Two dedicated pins expose the differential USB data lines:

| MCU pin | Name | Net label | USB signal |
|---|---|---|---|
| 21 | PA11 / USB_DM | USB_D- | D− (data minus) |
| 22 | PA12 / USB_DP | USB_D+ | D+ (data plus)  |

These net labels were introduced in the schematic alongside the crystal circuit (0003)
to connect the MCU USB pins to the physical connector added in this change.

A USB Micro-B receptacle (J1) is used as the physical interface. Micro-B is the
prevalent connector on STM32 development boards and is consistent with the Blue Pill
form factor this project references.

---

## Circuit

### Connector pinout — J1 (`Connector:USB_B_Micro`)

| Pin | Name | Connected to | Notes |
|-----|---|---|---|
| 1 | VBUS | VBUS power net | 5 V supply from USB host |
| 2 | D− | USB_D− net label | → MCU PA11 (pin 21) |
| 3 | D+ | USB_D+ net label | → MCU PA12 (pin 22); also R2 pull-up |
| 4 | ID | No-connect | OTG host/device detect — not used |
| 5 | GND | GND | USB signal return / power return |
| 6 | Shield | No-connect | Mechanical shell — tied to GND on PCB  |

> Pin 6 (shield) is left as no-connect on the schematic symbol; it should be connected
> to the GND copper pour on the PCB through a short trace or thermal relief to provide
> shielding without creating a ground loop.

### D+ pull-up — R2 (1.5 kΩ)

```
+3.3V
  │
 R2  1.5 kΩ
  │
  ├──── USB_D+ ──── J1 pin 3 ──── [cable] ──── host D+
  │
 MCU PA12 (USB_DP, pin 22)
```

```
J1 pin 2 ──── USB_D− ──── MCU PA11 (USB_DM, pin 21)

J1 pin 1 ──── VBUS
J1 pin 5 ──── GND
```

### Power net topology

| Net | Source | Voltage | Description |
|---|---|---|---|
| VBUS | J1 pin 1 | 5 V | USB bus voltage, supplied by the USB host |
| +3.3V  | Voltage reg. | 3.3 V | Regulated MCU supply (regulator fed from VBUS) |

VBUS and +3.3V are separate nets. The 3.3 V regulator (not shown in this sub-circuit)
is powered from VBUS. The D+ pull-up R2 connects to the regulated +3.3V rail, not to
VBUS directly.

---

## Component Rationale

### J1 — USB Micro-B receptacle

USB Micro-B is chosen for physical compatibility with standard USB cables used on
Blue Pill-style STM32 boards. The 5-pin + shell connector provides VBUS, D−, D+, and
GND signals. The ID pin (pin 4) is unused because only USB device mode is implemented;
OTG host-detection (which requires reading the ID pin level) is not used.

### R2 — 1.5 kΩ D+ pull-up

USB Full Speed device enumeration is signalled to the host by pulling D+ to 3.3 V
through a 1.5 kΩ resistor. When the host detects this pull-up it identifies the
attached device as Full Speed (12 Mbps) and initiates enumeration.

USB 2.0 specification §7.1.5 defines:
- **Full Speed device:** 1.5 kΩ ± 5 % pull-up on D+ to V(OPR) (3.0–3.6 V).
- **Low Speed device:** 1.5 kΩ ± 5 % pull-up on D− to V(OPR).

The 1.5 kΩ value (E96 standard: 1500 Ω, E24 nearest: 1.5 kΩ) is specified directly;
0402 SMD footprint is consistent with the rest of the board passives.

> **Note on software-controlled pull-up:** The STM32F103 does not have an integrated
> programmable pull-up on USB_DP. The external resistor R2 is required. Some STM32
> designs add a GPIO-controlled transistor to disconnect R2 under software control (to
> force USB re-enumeration without a power cycle). This is not implemented here; if
> required, a small NPN or N-FET in series with R2 between D+ and +3.3V can be added.

---

## USB Clock Requirement

The USB peripheral requires a precise 48 MHz USB clock, which must be derived from
the PLL. With the 16 MHz HSE crystal added in 0003:

$$48\,\text{MHz} = \frac{16\,\text{MHz}}{2} \times 6 = 8\,\text{MHz} \times 6$$

This is configured in firmware via the RCC registers:
- `PLLSRC` = HSE / 2 (PREDIV1 = /2) → 8 MHz PLL input
- `PLLMUL` = × 6 → 48 MHz (USB clock via `USBPRE` = /1)
- `PLLMUL` = × 9 → 72 MHz SYSCLK (simultaneously)

> The USB peripheral cannot be clocked from the HSI RC oscillator (±1 % accuracy is
> insufficient for USB timing). The 16 MHz crystal in 0003 is therefore a prerequisite
> for USB operation.

---

## PCB Placement and Routing Notes

Per ST AN4879:

- Route D+ and D− as a **differential pair** with matched length (< 0.2 mm mismatch)
  and 90 Ω differential impedance (≈ 45 Ω single-ended on a standard 1.6 mm FR4 2-layer
  board: ~0.2 mm trace width, 0.2 mm spacing).
- Keep USB traces away from the crystal/oscillator circuit (0003), SPI clock lines, and
  switching regulator traces.
- Place R2 close to J1 pin 3, not near the MCU, to keep the stub length short.
- A ground pour or ground stitching vias along the D+/D− traces reduces EMI.
- The VBUS trace must be rated for 500 mA (USB 2.0 max) — a 0.3 mm trace is sufficient
  on 1 oz copper for short distances.
- Add a 100 nF decoupling capacitor on VBUS close to J1 pin 1 if the regulator input
  capacitor is far from the connector.

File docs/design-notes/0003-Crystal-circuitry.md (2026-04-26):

# 0003 — HSE Crystal Oscillator Circuit (STM32F103C8T6)

**Date:** 2026-04-26
**Status:** Implemented
**References:**
- ST AN2867 — *Oscillator design guide for STM8S, STM8A and STM32 microcontrollers*
- `docs/datasheets/16MHz-SMD-Crystal-oscillator.png`
- `docs/datasheets/Oscillator-design-guide-for-STM8S-STM8A-and-STM32-microcontrollers-ST-MICRO-1.pdf`

---

## Bill of Materials (machine-readable)

| Ref | Value | lib_id | Footprint | Datasheet |
|-----|---|---|---|---|
| Y1  | 16MHz | Device:Crystal_GND24 | Crystal:Crystal_SMD_3225-4Pin_3.2x2.5mm | ~ |
| C10 | 10p | Device:C | Capacitor_SMD:C_0402_1005Metric | ~ |
| C11 | 10p | Device:C | Capacitor_SMD:C_0402_1005Metric | ~ |

---

## Context

The STM32F103C8T6 has two high-speed external oscillator pins that support a crystal
resonator circuit for generating the HSE (High Speed External) clock:

| MCU pin | Name | Net label | Description |
|---|---|---|---|
| 12 | PD0/OSC_IN  | HSE_IN | Crystal input / amplifier output |
| 13 | PD1/OSC_OUT | HSE_OUT | Crystal output / amplifier input |

A 16 MHz HSE crystal is the preferred clock source because it allows the internal PLL
to reach the maximum 72 MHz SYSCLK (via the /2 HSE prescaler and ×9 PLL multiplier),
while remaining more stable and accurate than the internal RC oscillator (HSI, ±1 %
over temperature vs < ±50 ppm for a crystal).

The symbol used is `Device:Crystal_GND24` — a four-pin crystal package where pins 2 and
4 are the grounded case pads. This matches common 4-pad SMD crystal packages (e.g.
3225, 5032) in which the two long-side case pads are tied to GND for shielding.

---

## Circuit

### Topology

The STM32 integrates a Pierce oscillator amplifier on the OSC_IN/OSC_OUT pin pair.
Two external load capacitors (C10, C11) complete the resonant tank circuit:

```
MCU PD0 (OSC_IN)                                           MCU PD1 (OSC_OUT)
    │                                                               │
[HSE_IN net] ──────────────────────────────────────────── [HSE_OUT net]
    │                                                               │
    ├── Y1 pin 1 ──────── [crystal Y1 16 MHz] ────── Y1 pin 3 ────┤
    │                      Y1 pins 2, 4 → GND                      │
    │                                                               │
   C11 10p                                                        C10 10p
    │                                                               │
   GND ──────────────────────────────────────────────────────────GND
```

Y1 pins 2 and 4 (case/GND pads) are tied together and connected to the same GND node
as the bottom plates of C10 and C11.

### Net Labels

| Label | Connects |
|---|---|
| HSE_IN  | Y1 pin 1 ↔ MCU OSC_IN (PD0, pin 12)  |
| HSE_OUT | Y1 pin 3 ↔ MCU OSC_OUT (PD1, pin 13) |

Net labels are used rather than direct wires to keep the schematic readable; the
crystal sub-circuit and the MCU symbol are on different areas of the sheet.

---

## Component Rationale

### Y1 — 16 MHz crystal

A 16 MHz fundamental-mode crystal is chosen as the HSE source:

- 16 MHz is within the HSE frequency range of the STM32F103 (4–16 MHz for the
  internal oscillator drive circuit in the default gain mode).
- 16 MHz → SYSCLK 72 MHz path: HSE/2 = 8 MHz feeds the PLL; PLL ×9 = 72 MHz.
- Fundamental mode at 16 MHz avoids the overtone circuit complexity needed above
  ~30 MHz.

The 4-pin GND24 package provides EMI shielding through the grounded case pads, which
is preferred on a compact PCB where the crystal sits near the MCU.

### C10, C11 — 10 pF load capacitors

The two load capacitors form the feedback network of the Pierce oscillator. The
effective load capacitance seen by the crystal is:

$$C_{L,\text{eff}} = \frac{C_{10} \times C_{11}}{C_{10} + C_{11}} + C_{\text{stray}}$$

With C10 = C11 = 10 pF and an estimated PCB stray capacitance of ~3 pF per node on a
compact 0402 layout:

$$C_{L,\text{eff}} = \frac{10 \times 10}{10 + 10} + 3 \approx 8 \text{ pF}$$

This targets a crystal with a specified load capacitance of **8 pF**, which is common
for small SMD 16 MHz crystals. Verify the selected crystal's CL specification and
adjust C10/C11 if required:

$$C_{\text{ext}} = 2 \times (C_L - C_{\text{stray}})$$

| Crystal CL | Cstray (est.) | C10 = C11 required |
|---|---|---|
| 8 pF | 3 pF | 10 pF |
| 12 pF | 3 pF | 18 pF |
| 16 pF | 3 pF | 26 pF (→ 27 pF std value) |

Per ST AN2867 §3.2, using values lower than required reduces startup reliability;
values higher than required increase drive level and may violate the crystal's maximum
drive power (typically 100–500 µW for SMD 16 MHz parts).

---

## Placement Notes

- Place Y1 and C10/C11 as a tightly grouped cluster, as close to MCU pins 12/13 as
  possible (< 5 mm recommended).
- Route HSE_IN and HSE_OUT traces short and direct; minimise trace length to reduce
  stray capacitance and loop area.
- The GND connection for C10, C11 and Y1 case pads must use a short, direct via to the
  ground plane — do **not** share a single via between all three; each component should
  have its own GND via.
- Keep the crystal circuit away from high-frequency switching traces (SPI, I2C, USB
  D+/D−). A keep-out zone under the crystal is recommended on dense boards.
- Do **not** route any signal traces under the crystal body.

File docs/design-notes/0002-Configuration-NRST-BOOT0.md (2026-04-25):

# 0002 — Configuration Pins: NRST & BOOT0

## Bill of Materials (machine-readable)
| Ref | Value | lib_id | Footprint | Datasheet |
|-----|---|---|---|---|
| C9  | 100n | Device:C | Capacitor_SMD:C_0402_1005Metric | ~ |
| R1  | 10k  | Device:R | Resistor_SMD:R_0402_1005Metric | ~ |
| SW1 | SW_SPDT | Switch:SW_SPDT | Connector_PinHeader_2.54mm:PinHeader_1x03_P2.54mm_Vertical | ~ |

---

## Context

The STM32F103C8T6 has two dedicated configuration pins that control the boot mode and
the external reset behaviour. Both must be handled correctly to ensure reliable startup
and a usable programming/debugging workflow.

---

## NRST — External Reset Filter

### Pin

| MCU pin | Name | Type |
|---|---|---|
| 7 | NRST | I/O, active-low reset |

### Circuit

```
NRST (net) ─────┬──── to MCU pin 7
                │
               C9 100n
                │
               GND
```

### Component

| Ref | Value | Footprint |
|-----|---|---|
| C9  | 100n  | Capacitor_SMD:C_0402_1005Metric |

### Rationale

The STM32 datasheet recommends a 100 nF filter capacitor on NRST. It serves two purposes:

1. **Noise immunity** — absorbs fast voltage transients on the reset line that could cause
   a spurious reset during normal operation.
2. **Reset pulse shaping** — ensures the reset pulse width meets the minimum requirement
   (typ. 300 µs for the internal reset circuit to latch).

The NRST net is also routed as a named label so that it can be wired to a debug connector
(e.g. SWD 10-pin header pin 10) without a long wire crossing the sheet.

### Reference

- STM32F103C8 datasheet §5.3.13: NRST — external reset pin with internal pull-up (~40 kΩ).

---

## BOOT0 — Boot Mode Selection

### Pins

| MCU pin | Name  | Boot mode control |
|---|---|---|
| 44 | BOOT0 | Selects boot source together with BOOT1 (PB2) |

### Boot Mode Truth Table

| BOOT1 (PB2) | BOOT0 | Boot source |
|---|---|---|
| x | 0 | Main Flash (normal operation) |
| 0 | 1 | System memory — ST factory bootloader (UART/SPI/I2C/USB DFU) |
| 1 | 1 | Embedded SRAM |

### Circuit

```
+3.3V ──┐
        │ (SW1 position A)
        SW1 (SPDT)
        │ (SW1 position B)
GND ────┘
        │
        │ SW_BOOT0 (net)
        │
       R1 10k (series)
        │
        │ BOOT0 (net)
        │
       ─┴─ to MCU pin 44
```

### Components

| Ref | Value | Footprint | Notes |
|-----|---|---|---|
| SW1 | SW_SPDT | Connector_PinHeader_2.54mm:PinHeader_1x03_P2.54mm_Vertical | 3-pin header + jumper for prototype |
| R1  | 10k | Resistor_SMD:R_0402_1005Metric | Series protection + override resistor |

### Rationale

**SW1 — SPDT boot mode switch**

A single-pole double-throw switch (implemented here as a 3-pin header with a jumper)
ties BOOT0 to either GND or +3.3V:

- **GND position (normal)** — BOOT0 = 0, MCU boots from main Flash. This is the default
  position for production and normal development use.
- **+3.3V position (bootloader)** — BOOT0 = 1, MCU enters the ST factory bootloader stored
  in system memory. This allows programming via UART (PA9/PA10) without a dedicated
  SWD programmer.

A header + jumper was chosen over a DIP switch for prototype convenience. On a production
board this may be replaced with a SMD slide switch or a pull-down resistor only (if
SWD programming is the sole programming path and no UART DFU is needed).

**R1 — 10 kΩ series resistor**

The series resistor between the switch and the BOOT0 pin serves two purposes:

1. **Short-circuit protection** — if the switch momentarily shorts +3.3V to GND during
   switching (break-before-make gap), R1 limits the transient current.
2. **ST-Link / external override** — when the MCU is already running and an external tool
   drives BOOT0 (e.g. some programmers can assert BOOT0 before reset), R1 allows the
   tool to override the switch position without fighting it. At 10 kΩ, the switch is
   a weak driver that any pushed output can easily overcome.

### Notes

- BOOT1 (PB2) is not broken out in this design. It defaults to GND via the MCU internal
  state after reset (input with internal weak pull, floats low if unconnected — verify
  on board bring-up).
- The BOOT0 footprint for SW1 is a 3-pin vertical 2.54 mm pin header. A 2-pin jumper
  placed between pins 1–2 selects GND; between pins 2–3 selects +3.3V. Mark the header
  silkscreen accordingly.

### Reference

- STM32F103C8 datasheet §3.4: Boot configuration.
- AN2606 §33: STM32F10xxx system memory boot mode (UART bootloader).

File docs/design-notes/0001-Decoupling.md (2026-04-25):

# 0001 — Power Decoupling Network (STM32F103C8T6)

**Date:** 2026-04-25
**Status:** Implemented
**References:** ST AN2834 — *How to achieve EMC compliance with STM32 microcontrollers*

---

## Bill of Materials (machine-readable)

| Ref | Value | lib_id | Footprint | Datasheet |
|-----|---|---|---|---|
| U1  | STM32F103C8T6 | MCU_ST_STM32F1:STM32F103C8Tx | Package_QFP:LQFP-48_7x7mm_P0.5mm | https://www.st.com/resource/en/datasheet/stm32f103c8.pdf |
| FB1 | 120R | Device:FerriteBead | Inductor_SMD:L_0402_1005Metric | ~ |
| C1  | 100n | Device:C | Capacitor_SMD:C_0402_1005Metric | ~ |
| C2  | 100n | Device:C | Capacitor_SMD:C_0402_1005Metric | ~ |
| C3  | 100n | Device:C | Capacitor_SMD:C_0402_1005Metric | ~ |
| C4  | 100n | Device:C | Capacitor_SMD:C_0402_1005Metric | ~ |
| C5  | 10u  | Device:C | Capacitor_SMD:C_0402_1005Metric | ~ |
| C6  | 10n  | Device:C | Capacitor_SMD:C_0402_1005Metric | ~ |
| C7  | 1u | Device:C | Capacitor_SMD:C_0402_1005Metric | ~ |
| C8  | 1u | Device:C | Capacitor_SMD:C_0402_1005Metric | ~ |

---

## Context

The STM32F103C8T6 (LQFP-48) has two separate supply domains that require independent
decoupling strategies:

| Domain | Pins | Description |
|---|---|---|
| VDD | pins 19, 32, 48 | Digital core and I/O supply |
| VDDA | pin 5 | Analog supply (ADC, DAC, PLL, RC oscillator) |
| VBAT | pin 1 | Backup domain (RTC, backup registers) |

ST strongly recommends isolating VDDA from VDD with a ferrite bead to prevent digital
switching noise from corrupting ADC measurements (AN2834, section 2.2).

---

## Decoupling Network — Component List

### Digital supply (VDD → +3.3V rail)

| Ref | Value | Purpose |
|---|---|---|
| C1 | 100 nF | Local HF decoupling, VDD pin 19 |
| C2 | 100 nF | Local HF decoupling, VDD pin 32 |
| C3 | 100 nF | Local HF decoupling, VDD pin 48 |
| C4 | 100 nF | Local HF decoupling, VBAT pin 1 |
| C5 | 10 µF  | Bulk reservoir capacitor for VDD rail |

> One 100 nF ceramic cap per VDD/VBAT pin, placed as close as possible to the pin.
> Bulk cap C5 handles slower load transients from GPIO toggling and peripheral startup.

### Analog supply (VDDA → +3.3VA filtered rail)

| Ref | Value | Purpose |
|---|---|---|
| FB1 | 120 Ω @ 100 MHz | Ferrite bead — isolates VDDA from VDD digital noise |
| C7  | 1 µF  | Low-frequency filtering on VDDA (after ferrite) |
| C8  | 1 µF  | Additional bulk on VDDA node |
| C6  | 10 nF | High-frequency filtering on VDDA |

> The ferrite bead FB1 (120 Ω at 100 MHz) creates a low-pass filter together with C6/C7/C8.
> This prevents digital switching transients on +3.3V from coupling into the ADC reference.

---

## Power Rail Topology

```
+3.3V ──────┬──── C5 (10µF) ──── GND       ← Bulk
            ├──── C1 (100n) ──── GND        ← VDD pin 19
            ├──── C2 (100n) ──── GND        ← VDD pin 32
            ├──── C3 (100n) ──── GND        ← VDD pin 48
            ├──── C4 (100n) ──── GND        ← VBAT pin 1
            │
            └── FB1 (120R) ─┬─ +3.3VA
                            ├── C7 (1µF)  ── GND
                            ├── C8 (1µF)  ── GND
                            └── C6 (10nF) ── GND   → VDDA pin 5
```

---

## Design Decisions

### Why 100 nF for VDD pins?
100 nF ceramic (X7R/X5R) provides low impedance in the 1–100 MHz range where MCU
switching transients occur. Per ST reference designs and AN2834.

### Why 10 µF bulk?
Handles slower load steps (e.g., when multiple GPIO ports switch simultaneously or a
peripheral is enabled). One bulk cap is sufficient for a single-supply LQFP-48 board.

### Why 120 Ω ferrite bead for VDDA?
The impedance at 100 MHz is high enough to block digital noise while DC resistance is
low enough (typically < 0.5 Ω) not to cause significant voltage drop at VDDA currents
(< 10 mA typical for ADC use). Higher impedance beads (600 Ω+) could cause supply
instability under transient load.

### Why 10 nF on VDDA in addition to 1 µF?
The two cap values cover different frequency bands. 1 µF handles lower frequencies;
10 nF maintains low impedance above ~10 MHz where ferrite bead effectiveness drops off.

### Footprints
All capacitors: 0402 (1005 metric). Selected for compact placement near MCU pins.
Ferrite bead FB1: 0402.

---

## Placement Notes

- All VDD decoupling caps must be placed on the **same side as the MCU**, within 1–2 mm
  of each VDD/GND pin pair.
- FB1 + VDDA caps form an island: route +3.3VA trace short and keep it away from
  high-speed signal traces (SPI, I2C, USART).
- GND via directly under each cap recommended (single via per cap, not shared).

---

## References

- ST AN2834 — *How to achieve EMC compliance with STM32 microcontrollers*
  https://www.st.com/resource/en/application_note/an2834-how-to-achieve-emc-compliance-with-stm32-microcontrollers-stmicroelectronics.pdf
- STM32F103C8T6 Datasheet — see `docs/datasheets/`
- ST Reference Manual RM0008

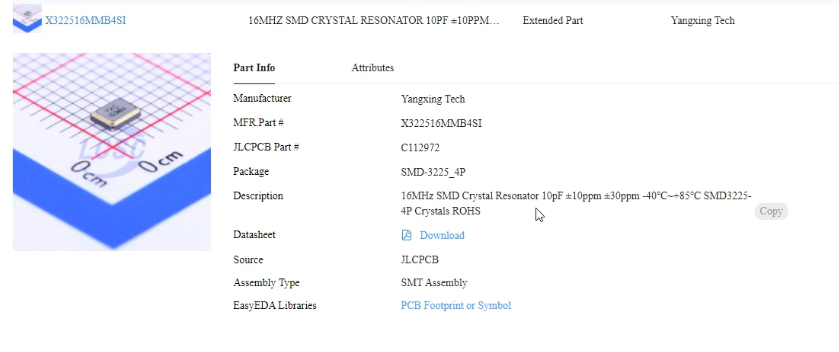
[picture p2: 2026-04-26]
docs/datasheets/16MHz-SMD-Crystal-oscillator.png

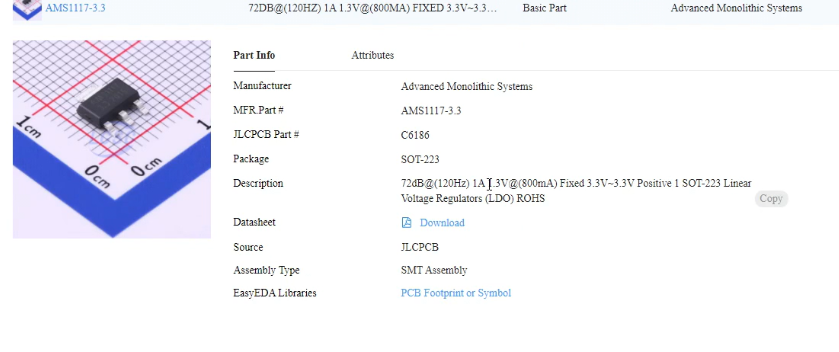
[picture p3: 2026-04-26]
docs/datasheets/AMS1117-3-3 Linear-Voltage-Regulator.png

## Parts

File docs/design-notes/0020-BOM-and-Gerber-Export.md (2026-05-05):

# 0020 — BOM and Gerber Export — Final Stage

**Date:** 2026-05-05
**Status:** Complete — **This is the final design note. The board is ready for fabrication.**
**References:** All previous design notes 0001–0019; KiCad 9 Gerber export documentation

---

## Summary

All manufacturing outputs have been generated from the completed PCB design and committed
to the `manufacturing/` directory. This marks the end of the design cycle for the
STM32F103C8T6 development board. The board is ready to be submitted to a PCB fabrication
house.

---

## 1 — Bill of Materials (`manufacturing/tproject.csv`)

Exported from KiCad Schematic Editor → **File → Export → BOM**.

| Ref(s) | Qty | Value | Footprint | Datasheet |
|---|-----|---|---|---|
| C1, C2 | 2 | 22 µF | C_0805_2012Metric | — |
| C3 | 1 | 10 µF | C_0603_1608Metric | — |
| C4, C5, C6, C7, C11 | 5 | 100 nF | C_0402_1005Metric | — |
| C8 | 1 | 10 nF | C_0402_1005Metric | — |
| C9, C10 | 2 | 1 µF | C_0402_1005Metric | — |
| C12, C13 | 2 | 10 pF | C_0402_1005Metric | — |
| D1 | 1 | RED LED | LED_0603_1608Metric | — |
| FB1 | 1 | 120 Ω ferrite bead | L_0603_1608Metric | — |
| H1–H4 | 4 | Mounting hole M2 | MountingHole_2.2mm_M2 | — (excluded from BOM) |
| J1 | 1 | USB Micro-B | USB_Micro-B_Wuerth_629105150521 | — |
| J2, J3, J4 | 3 | Conn_01x04 | PinHeader_1x04_P2.54mm_Vertical | — |
| R1, R3, R4, R5 | 4 | 1k5 | R_0402_1005Metric | — |
| R2 | 1 | 10k | R_0402_1005Metric | — |
| SW1 | 1 | SW_SPDT | SW_SPDT_PCM12 | — |
| U1 | 1 | STM32F103C8T6 | LQFP-48_7x7mm_P0.5mm | ST datasheet |
| U2 | 1 | AMS1117-3.3 | SOT-223-3_TabPin2 | AMS datasheet |
| Y1 | 1 | 16 MHz crystal | Crystal_SMD_3225-4Pin_3.2x2.5mm | — |

**Total unique line items:** 17 (excluding mounting holes)
**Total component placements:** 29 (excluding H1–H4)

---

## 2 — Gerber and Drill Files (`manufacturing/`)

Exported from KiCad PCB Editor → **File → Fabrication Outputs → Gerbers** and
**Drill Files**. All files are also bundled in `tproject.zip` for direct submission
to a fab house.

### 2.1 — Gerber layers

| File | Layer | Size |
|---|---|---|
| `tproject-F_Cu.gbr` | Front copper | 28 KB |
| `tproject-B_Cu.gbr` | Back copper (GND plane) | 74 KB |
| `tproject-F_Mask.gbr` | Front solder mask | 6.9 KB |
| `tproject-B_Mask.gbr` | Back solder mask | 1.5 KB |
| `tproject-F_Paste.gbr` | Front solder paste (stencil) | 6.0 KB |
| `tproject-B_Paste.gbr` | Back solder paste | 491 B |
| `tproject-F_Silkscreen.gbr` | Front silkscreen | 46 KB |
| `tproject-B_Silkscreen.gbr` | Back silkscreen | 9.9 KB |
| `tproject-Edge_Cuts.gbr` | Board outline (38.54 × 33.17 mm) | 1012 B |
| `tproject-job.gbrjob` | Gerber job file (layer stack description) | — |

### 2.2 — Drill files

| File | Type | Content |
|---|---|---|
| `tproject-PTH.drl` | Plated through-holes | Pin header holes (J2, J3, J4), crystal pads |
| `tproject-NPTH.drl` | Non-plated through-holes | M2 mounting holes (H1–H4) |

### 2.3 — Pick-and-place (centroid) files

| File | Side | Components |
|---|---|---|
| `tproject-top-pos.csv` | Top (F.Cu) | All 29 placed components |
| `tproject-bottom-pos.csv` | Bottom | Empty — no bottom-side components |

---

## 3 — Board Summary

| Parameter | Value |
|---|---|
| Board dimensions | 38.54 × 33.17 mm |
| Layers | 2 (F.Cu signal + B.Cu GND plane) |
| Min track width | 0.2 mm (USB D+/D−), 0.3 mm (all other signals) |
| Min clearance | 0.2 mm |
| Drill sizes | 1.0 mm (PTH pin headers), 2.2 mm (NPTH M2) |
| Surface finish | As ordered (HASL or ENIG recommended) |
| MCU | STM32F103C8T6, LQFP-48 |
| Supply | 5 V via USB Micro-B → AMS1117-3.3 → 3.3 V |

---

## 4 — Design Cycle Summary

| Note | Stage |
|---|---|
| 0001 | Decoupling strategy |
| 0002 | NRST / BOOT0 configuration |
| 0003 | HSE crystal circuitry |
| 0004 | USB Micro-B connector |
| 0005 | Power supply and connectors |
| 0006 | ERC and annotations |
| 0007 | Footprint assignment |
| 0008 | PCB setup and design rules |
| 0009 | Initial component placement |
| 0010 | USB / SWO placement refinement |
| 0011 | SMD switch and USB STEP model |
| 0012 | Switch / connector placement refinement |
| 0013 | Power supply cluster placement |
| 0014 | Board outline and mounting holes |
| 0015 | Routing — decoupling caps and HSE crystal |
| 0016 | Connector footprint fix (J2, J3, J4) |
| 0017 | Routing — signal nets (UART, I2C, SWD, USB, BOOT0) |
| 0018 | Routing — power nets |
| 0019 | Silkscreen and zone fill |
| **0020** | **BOM and Gerber export — final stage** |

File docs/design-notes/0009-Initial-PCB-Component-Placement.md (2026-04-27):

# 0009 — Initial PCB Component Placement (STM32F103C8T6)

**Date:** 2026-04-27
**Status:** Implemented
**References:** Design notes 0001–0008; STM32F103C8T6 datasheet (DS5319); ST AN2867 (oscillator design)

---

## Summary

All 26 schematic components were placed on the PCB front copper layer (F.Cu) in a single
session. No board outline (Edge.Cuts), no copper routes, and no vias exist yet — this
commit establishes the component floorplan that will drive the subsequent routing phase.

The layout is organised into three functional clusters plus a peripheral group:

| Cluster | Centre (mm) | Contents |
|---|---|---|
| MCU + crystal | (51, 67) | U1, Y1, C4, C7, C8, C9, C10, C12, C13, FB1, R5 |
| Power supply | (118, 57) | U2, J1, C1, C2, C3, C5, C6, D1, R1 |
| Control / interface | (107, 58) | SW1, R2, R3, R4, C11 |
| Expansion connectors | (119, 55) | J2, J3, J4 |

---

## 1 — Floorplan Overview

Approximate top-view layout (Y axis down, units mm, not to scale):

```
X →   38        50        60        100       116       125
      |         |         |         |         |         |
  38  R5        C7        .         .         .         .
      .         .         .         .         .         .
  44  .         .         .         .         C1        .
      .         .         .         .         .         .
  47  .         .         .         .         J1  C2    .
      .         .         .         .         .         .
  50  .         .         .         .         D1        .
      .         .         .         .         .         .
  55  .         .         .         J2  J3    .    J4   .
      .         .         .         .         .         .
  60  .    C4   .         .         .   U2    .         .
      .         .         .   SW1   .         .         .
  63  .         .         .         R1        .         .
      .         .         .         R2        .         .
  66  Y1  C12   .         .         R3        C5        .
      .    .    U1        .         R4        .         .
  68  .   C13   .         .         .         .   C6  C11
      .         .         .         .         C3        .
  72  .    FB1  .         .         .         .         .
      .   C9    .         .         .         .         .
  74  .   C10   .         .         .         .         .
```

---

## 2 — Component Placement Table

All components placed on **F.Cu** (top face). Coordinates are KiCad PCB origin (mm).

### MCU cluster

| Ref  | Value | Footprint | X (mm) | Y (mm) | Rot (°) | Role |
|---|---|---|---|---|---|---|
| U1 | STM32F103C8T6 | LQFP-48 7×7 mm |  56.00 |  67.25 | 0 | Main MCU |
| C4 | 100 nF | 0402 |  50.00 |  63.00 | 90 | VDD decoupling — above-left |
| C7 | 100 nF | 0402 |  53.48 |  60.00 | 0 | VDD decoupling — above |
| C8 | 10 nF | 0402 |  49.75 |  67.52 | 90 | VDDA HF decoupling |
| C9 | 1 µF | 0402 |  49.27 |  72.08 |  180 | VDDA bulk decoupling |
| C10  | 1 µF | 0402 |  49.27 |  73.58 |  180 | VDDA bulk decoupling |
| FB1  | 120 Ω (ferrite) | L_0603 |  51.25 |  72.54 |  −90 | VDD power-line filter |

### Crystal cluster

| Ref  | Value | Footprint | X (mm) | Y (mm) | Rot (°) | Role |
|---|---|---|---|---|---|---|
| Y1 | 16 MHz  | Crystal_SMD_3225-4Pin |  45.00 |  67.42 |  −90 | HSE crystal |
| C12  | 10 pF | 0402 |  47.75 |  66.04 | 90 | HSE load cap (OSC_IN side) |
| C13  | 10 pF | 0402 |  47.75 |  68.79 | 90 | HSE load cap (OSC_OUT side) |

### I²C pull-up (left of board)

| Ref  | Value | Footprint | X (mm) | Y (mm) | Rot (°) | Role |
|---|---|---|---|---|---|---|
| R5 | 1.5 kΩ  | 0402 |  39.70 |  68.32 | 0 | I2C2 SDA pull-up |

### Power supply cluster

| Ref  | Value | Footprint | X (mm)  | Y (mm)  | Rot (°) | Role |
|---|---|---|---|---|---|---|
| U2 | AMS1117-3.3  | SOT-223-3 | 116.29  |  62.34  | 0 | 3.3 V LDO |
| C1 | 22 µF | 0805 | 124.53  |  44.35  | 0 | +3.3 V output bulk cap |
| C2 | 22 µF | 0805 | 124.53  |  47.36  | 0 | VBUS input bulk cap |
| C3 | 10 µF | 0603 | 118.62  |  67.71  | 0 | VDD/VDDA intermediate bulk |
| C5 | 100 nF | 0402 | 122.65  |  66.00  | 0 | LDO output HF bypass |
| C6 | 100 nF | 0402 | 122.65  |  71.00  | 0 | LDO output HF bypass |
| D1 | RED LED | LED_0603 | 124.35  |  50.16  | 0 | Power indicator |
| R1 | 1.5 kΩ | 0402 | 108.54  |  61.72  | 0 | LED current limiter |

### Control / interface cluster

| Ref  | Value | Footprint | X (mm)  | Y (mm)  | Rot (°) | Role |
|---|---|---|---|---|---|---|
| SW1  | SW_SPDT | SW_E-Switch_EG1224_SPDT_Angled |  99.60  |  46.46  | 0 | BOOT0 select switch (THT) |
| R2 | 10 kΩ | 0402 | 108.54  |  63.71  | 0 | BOOT0 series resistor |
| R3 | 1.5 kΩ | 0402 | 108.54  |  65.70  | 0 | USB D+ pull-up |
| R4 | 1.5 kΩ | 0402 | 108.54  |  67.69  | 0 | I2C2 SCL pull-up |
| C11  | 100 nF | 0402 | 125.52  |  71.00  | 0 | NRST filter cap |
| J1 | USB Micro-B| USB_Micro-B_Wuerth_629105150521  | 116.83  |  46.71  | 0 | USB connector |

### Expansion connectors

| Ref  | Value | Footprint | X (mm)  | Y (mm) | Rot (°) |
|---|---|---|---|---|---|
| J2 | Conn_01x04_Pin | PinHeader_1x04_P1.00mm_Vertical_SMD | 114.14  |  55.11 | 0 |
| J3 | Conn_01x04_Pin | PinHeader_1x04_P1.00mm_Vertical_SMD | 119.69  |  55.11 | 0 |
| J4 | Conn_01x04_Pin | PinHeader_1x04_P1.00mm_Vertical_SMD | 125.24  |  55.11 | 0 |

---

## 3 — Placement Rationale

### 3.1 MCU (U1) and VDD decoupling

The STM32F103C8T6 LQFP-48 body is centred at **(56, 67.25)**. It has four VDD supply
pins (pins 1 VBAT, 24, 36, 48) and one VDDA analogue supply (pin 9).

**VDD decoupling strategy** (per design note 0001 and ST datasheet Table 5):

- **C4, C7** (100 nF 0402) — placed above U1, providing high-frequency bypassing for the
  VDD pins on the top side of the package. Minimum trace length is achieved with rotations
  oriented toward the nearest VDD pad.
- **FB1** (120 Ω ferrite bead, 0603) — placed below-left of U1 at (51.25, 72.54), in line
  with the AVDD/VDDA supply path. Ferrite bead isolates the analogue supply from digital
  switching noise on the VDD rail.
- **C8** (10 nF 0402) — placed left of U1 for VDDA high-frequency decoupling. The
  10 nF / 10 nF combination provides low impedance from ~100 MHz downward.
- **C9, C10** (1 µF 0402 × 2) — placed below-left of U1 for VDDA bulk energy storage
  (analogue supply stability under ADC conversions).

### 3.2 Crystal circuit (Y1, C12, C13)

The 16 MHz SMD crystal is placed at **(45, 67.42)**, rotated −90° so its long axis aligns
horizontally, keeping the pads close to U1's OSC_IN (PD0, pin 5) and OSC_OUT (PD1, pin 6)
on the left side of the package. Distance between Y1 and U1 centres: ≈ **11 mm**.

Load capacitors:

- **C12** (10 pF, 0402) at (47.75, 66.04) — OSC_IN side
- **C13** (10 pF, 0402) at (47.75, 68.79) — OSC_OUT side

Both rotated 90° and positioned symmetrically on either side of the crystal to keep trace
lengths balanced and parasitic capacitance equal on both oscillator pins (see design note
0003 for load capacitance calculation).

**R5** (1.5 kΩ I2C SDA pull-up) is placed at the far left (39.70, 68.32) alongside the
crystal cluster because PB11 (I2C2_SDA) exits the left side of the MCU package.

### 3.3 Power supply cluster

AMS1117-3.3 (**U2**, SOT-223-3) is placed at the right of the board, keeping the noisy
USB VBUS entry (J1) and 5 V→3.3 V conversion away from the analogue MCU circuitry on the
left side:

- **C1, C2** (22 µF 0805) — output and input bulk capacitors stacked vertically above U2,
  as required by the AMS1117 stability specification (≥ 10 µF on both VI and VO).
- **C5, C6** (100 nF 0402) — HF bypass directly beside U2 for LDO output impedance.
- **C3** (10 µF 0603) — intermediate bulk capacitor bridging the regulator output area with
  the main VDD distribution.
- **D1** (RED LED, 0603) + **R1** (1.5 kΩ) — power indicator placed in the top-right corner
  so it remains visible after the board is installed.

### 3.4 Control / interface area

- **SW1** (THT SPDT) — BOOT0 select switch, placed centrally to be reachable in assembled
  form; through-hole body confirmed against B.Cu keepout rules from design note 0008.
- **R2** (10 kΩ) — BOOT0 series, **R3** (1.5 kΩ) — USB D+ pull-up, **R4** (1.5 kΩ) — I2C
  SCL pull-up: stacked vertically at X = 108.54 for efficient routing to the right side of U1.
- **C11** (100 nF) — NRST filter cap, placed near the power supply cluster since NRST is
  routed to the right connector side.
- **J1** (USB Micro-B) — placed at the top edge, oriented outward for panel cut-out access.

### 3.5 Expansion connectors (J2, J3, J4)

Three 4-pin 1.00 mm pitch SMD pin headers are aligned at Y = 55.11 with a 5.55 mm pitch
between them, forming a contiguous 12-pin break-out row. This placement leaves the MCU
routing area clear and provides a consistent connector edge for a mating board or flex cable.

---

## 4 — Next Steps

1. **Draw board outline** on Edge.Cuts layer (dimensions TBD based on connector and SW1 envelope).
2. **Route copper** — power pour on B.Cu for GND, critical signals (USB D+/D−, OSC traces) first.
3. **Run DRC** after routing and verify all net connections and clearance rules (0.2 mm min,
   0.2 mm track per design note 0008).

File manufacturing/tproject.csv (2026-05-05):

Reference | Qty | Value | DNP | Exclude from BOM | Exclude from Board | Footprint | Datasheet
C1,C2 | 2 | 22u |  |  |  | Capacitor_SMD:C_0805_2012Metric | ~
C3 | 1 | 10u |  |  |  | Capacitor_SMD:C_0603_1608Metric | ~
C4,C5,C6,C7,C11 | 5 | 100n |  |  |  | Capacitor_SMD:C_0402_1005Metric | ~
C8 | 1 | 10n |  |  |  | Capacitor_SMD:C_0402_1005Metric | ~
C9,C10 | 2 | 1u |  |  |  | Capacitor_SMD:C_0402_1005Metric | ~
C12,C13 | 2 | 10p |  |  |  | Capacitor_SMD:C_0402_1005Metric | ~
D1 | 1 | RED |  |  |  | LED_SMD:LED_0603_1608Metric | ~
FB1 | 1 | 120R |  |  |  | Inductor_SMD:L_0603_1608Metric | ~
H1,H2,H3,H4 | 4 | MountingHole |  | Excluded from BOM |  | MountingHole:MountingHole_2.2mm_M2 | ~
J1 | 1 | USB_B_Micro |  |  |  | Connector_USB:USB_Micro-B_Wuerth_629105150521 | ~
J2,J3,J4 | 3 | Conn_01x04_Pin |  |  |  | Connector_PinHeader_2.54mm:PinHeader_1x04_P2.54mm_Vertical | ~
R1,R3,R4,R5 | 4 | 1k5 |  |  |  | Resistor_SMD:R_0402_1005Metric | ~
R2 | 1 | 10k |  |  |  | Resistor_SMD:R_0402_1005Metric | ~
SW1 | 1 | SW_SPDT |  |  |  | Button_Switch_SMD:SW_SPDT_PCM12 | ~
U1 | 1 | STM32F103C8T6 |  |  |  | Package_QFP:LQFP-48_7x7mm_P0.5mm | https://www.st.com/resource/en/datasheet/stm32f103c8.pdf
U2 | 1 | AMS1117-3.3 |  |  |  | Package_TO_SOT_SMD:SOT-223-3_TabPin2 | http://www.advanced-monolithic.com/pdf/ds1117.pdf
Y1 | 1 | 16MHz |  |  |  | Crystal:Crystal_SMD_3225-4Pin_3.2x2.5mm | ~

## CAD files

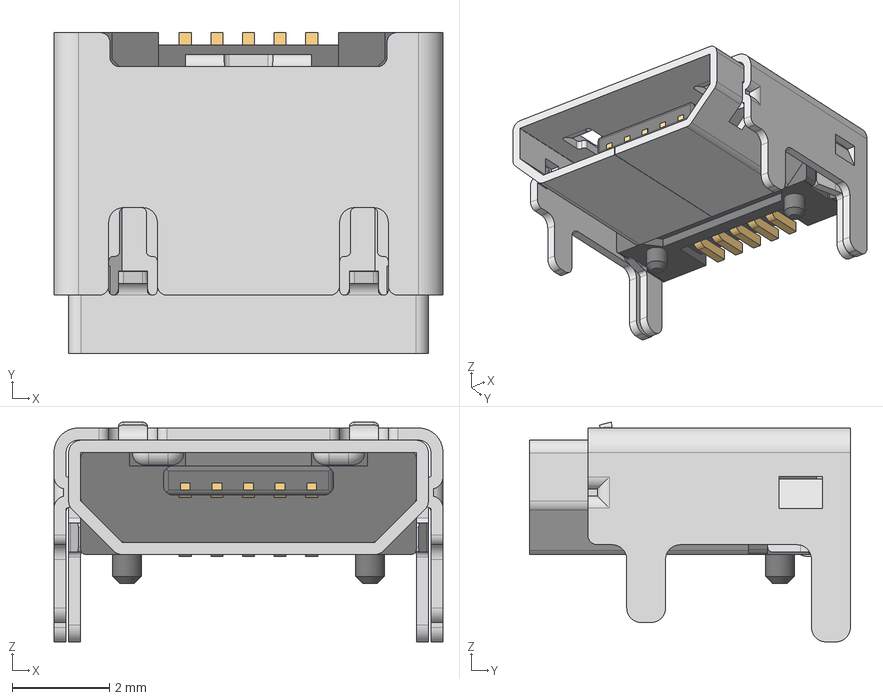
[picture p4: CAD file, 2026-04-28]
step/629105150521 (rev1).stp
8.00 x 6.60 x 4.52 mm
629105150521_Housing
629105150521_Pin1 x 4
629105150521_Pin2
629105150521_Shielding2
629105150521_Shielding

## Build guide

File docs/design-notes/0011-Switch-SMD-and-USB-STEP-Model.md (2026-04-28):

# 0011 — Switch Footprint Change (THT → SMD) and USB Connector STEP Model

**Date:** 2026-04-28
**Status:** Implemented
**References:** Design note 0002 (BOOT0 circuit), 0010 (USB placement); CK PCM12 datasheet (https://www.ckswitches.com/media/1424/pcm.pdf); Würth 629105150521 STEP rev1

---

## Summary

Two independent changes were made in this session:

1. **SW1 footprint replaced**: the large through-hole angled slide switch
   (`SW_E-Switch_EG1224_SPDT_Angled`) was replaced with the SMD ultraminiature slide
   switch (`SW_SPDT_PCM12`) from the CK PCM12 series. Both the schematic `Footprint`
   field and the PCB footprint were updated. Position is unchanged (99.595, 46.455).

2. **USB connector STEP model replaced**: the KiCad built-in placeholder STEP model for
   J1 (USB Micro-B Würth 629105150521) was replaced with the manufacturer-supplied STEP
   file added to the project's `step/` directory.

---

## 1 — Switch Footprint Change (SW1)

### Before / After

| Property | Before | After |
|---|---|---|
| Footprint | `Button_Switch_THT:SW_E-Switch_EG1224_SPDT_Angled` | `Button_Switch_SMD:SW_SPDT_PCM12` |
| Mount type | Through-hole (THT) | Surface mount (SMD) |
| Datasheet | E-Switch EG series (right angle) | CK PCM12 (right angle) — ckswitches.com |
| 3D model | `Button_Switch_THT.3dshapes/SW_E-Switch_EG1224_SPDT_Angled.step` | `Button_Switch_SMD.3dshapes/SW_SPDT_PCM12.step` |
| PCB position | (99.595, 46.455) rot=0° | (99.595, 46.455) rot=0° *(unchanged)* |

### PCM12 footprint geometry

Courtyard bounding box (from KiCad `F.CrtYd` data):

| Dimension | Value |
|---|---|
| Width (X) | 8.8 mm (−4.4 to +4.4) |
| Height (Y) | 5.85 mm (−2.45 to +3.4) |
| Body approx. | 4.0 mm × 2.5 mm (PCM12 series per datasheet) |

The EG1224 THT footprint had a significantly larger courtyard (≈ 11 × 7 mm plus
through-hole barrel clearances). The PCM12 SMD footprint reduces the occupied board area
by approximately **50 %** and eliminates the need for drilled through-holes.

### Schematic change

The `Footprint` property of symbol SW1 was updated in `tproject.kicad_sch`:

```
- (property "Footprint" "Button_Switch_THT:SW_E-Switch_EG1224_SPDT_Angled" ...)
+ (property "Footprint" "Button_Switch_SMD:SW_SPDT_PCM12" ...)
```

Net connections (GND, BOOT0, +3.3V via R2) are unchanged — the PCM12 is also an SPDT
slide switch with equivalent pin-out for this application.

### Rationale

The EG1224 is a 5-pin right-angle THT slide switch. Its through-hole barrels would have
required drilling on a 2-layer board and occupied a large courtyard zone, conflicting with
SMD component routing around the BOOT0 pull-up resistor (R2) cluster. The CK PCM12:

- Is fully SMD, consistent with the rest of the board (except J1 mounting tabs).
- Has the same SPDT topology required by the BOOT0 select circuit (design note 0002).
- Fits within the existing (99.595, 46.455) placement without repositioning.
- Requires no additional drilling.

---

## 2 — USB Connector STEP Model (J1)

### Change

The 3D model reference for J1 (USB Micro-B, Würth 629105150521) was changed from the
KiCad built-in placeholder to the manufacturer-supplied STEP file added to the project:

| | Before | After |
|---|---|---|
| Model path | `${KICAD9_3DMODEL_DIR}/Connector_USB.3dshapes/USB_Micro-B_Wuerth_629105150521.step` | `${KIPRJMOD}/step/629105150521 (rev1).stp` |
| Source | KiCad built-in library | Manufacturer STEP, rev1 (804 KB) |
| File added | — | `step/629105150521 (rev1).stp` |

`${KIPRJMOD}` resolves to the project root directory, making the reference portable
across machines that have the project checked out.

### Why use the manufacturer STEP

- The KiCad built-in model for this connector is a generic approximation.
- The Würth 629105150521 STEP (rev1) is the exact mechanical model from the manufacturer,
  including the through-hole mounting tabs, shell dimensions, and USB port opening.
- Using the exact model ensures accurate DRC 3D collision checks and correct board-edge
  alignment for the USB connector panel cut-out that will be defined in Edge.Cuts.

### File added to repository

```
step/
└── 629105150521 (rev1).stp   804 KB   Würth USB Micro-B 629105150521 STEP rev1
```

---

## 3 — File Changes Summary

| File | Change |
|---|---|
| `tproject.kicad_sch` | SW1 `Footprint` property updated (1 line) |
| `tproject.kicad_pcb` | SW1 footprint block replaced; J1 `model` path updated |
| `step/629105150521 (rev1).stp` | New file — manufacturer STEP model for J1 |

---

## 4 — Next Steps

1. Verify SW1 PCM12 courtyard does not overlap with neighbouring components after DRC.
2. Draw board outline (Edge.Cuts) — J1 rotation (90°) and position (70.8, 65.875) define
   the required USB connector panel cut-out location.
3. Begin copper routing: USB differential pair first (J1 → R3 → U1 PA11/PA12), then
   SWD/SWO (J3 → U1 PA13/PA14/PB3).

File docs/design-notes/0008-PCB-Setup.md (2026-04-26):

# 0008 — PCB Setup (STM32F103C8T6)

**Date:** 2026-04-26
**Status:** Implemented
**References:** IPC-2221B, JLCPCB/PCBWay standard 2-layer spec

---

## Summary

The KiCad PCB editor was opened for the first time and the board setup was configured.
Changes span two files:

- `tproject.kicad_pcb` — board stackup, layer definition, and plot parameters (was essentially empty)
- `tproject.kicad_pro` — board design rules, DRC severities, track/via presets, teardrop settings

No copper, no components, no routes exist yet — this commit establishes the manufacturing
and electrical constraints that all subsequent layout work must satisfy.

---

## 1 — Board Stackup (`tproject.kicad_pcb`)

### Layer count and physical stack

| Layer | Type | Thickness (mm) | Material |
|---|---|---|---|
| F.SilkS | Top Silk Screen | — | — |
| F.Paste | Top Solder Paste | — | — |
| F.Mask | Top Solder Mask | 0.010 | — |
| **F.Cu** | **Copper (signal)**| **0.035** | — |
| dielectric 1| Core | **1.510** | FR4, εᵣ = 4.5, tan δ = 0.02 |
| **B.Cu** | **Copper (power)** | **0.035** | — |
| B.Mask | Bottom Solder Mask | 0.010 | — |
| B.Paste | Bottom Solder Paste| — | — |
| B.SilkS | Bottom Silk Screen | — | — |

**Total board thickness:** 1.6 mm (standard)

Copper finish: **None** (bare copper / HASL by default at fab).
Tenting: via tenting **front and back** (soldermask over via holes).

### Layer roles

| KiCad layer | Role assigned |
|---|---|
| F.Cu (0) | Signal — MCU, connectors, small-signal traces |
| B.Cu (2) | Power — ground/power pours |

A 2-layer board is sufficient for this design given the component count (~30 parts)
and the relatively relaxed signal integrity requirements (USB FS 12 Mbit/s maximum).

### Enabled drawing/fab layers

F.Adhesive, B.Adhesive, F.Paste, B.Paste, F.Silkscreen, B.Silkscreen, F.Mask, B.Mask,
User.Drawings, User.Comments, User.Eco1/2, Edge.Cuts, Margin, F.Courtyard, B.Courtyard,
F.Fab, B.Fab, User.1–4.

---

## 2 — Design Rules (`tproject.kicad_pro`)

### Clearance and width constraints

| Rule | Value | Notes |
|---|---|---|
| `min_clearance` | 0.20 mm | Copper-to-copper minimum; typical JLCPCB standard spec |
| `min_track_width` | 0.20 mm | Minimum track width |
| `min_via_diameter` | 0.70 mm | Minimum via pad diameter |
| `min_via_annular_width` | 0.13 mm | Minimum annular ring (via drill to pad edge) |
| `min_through_hole_diameter` | 0.30 mm | Minimum drill size |
| `min_hole_to_hole` | 0.254 mm| Hole-to-hole spacing |
| `min_hole_clearance` | 0.25 mm | Hole to copper clearance |
| `min_copper_edge_clearance` | 0.0 mm  | (not yet constrained — set at layout) |
| `min_silk_clearance` | 0.0 mm  | (not yet constrained) |
| `solder_mask_to_copper_clearance` | 0.0 mm | Fab-side mask expansion |
| `max_error` | 0.005 mm| Arc-to-chord approximation tolerance |
| `pad_to_mask_clearance` | 0 | No extra mask clearance beyond footprint spec |

> The 0.2 mm / 0.2 mm (track width / clearance) rule set is the standard minimum for
> JLCPCB and most prototype fabs. It is also compatible with PCBWay, Aisler, and OSH Park.

### Track width presets (quick-select in router)

| Preset | Width | Intended use |
|---|---|---|
| Default (auto) | —  | Net-class driven |
| 0.3 mm | 0.30 mm | General signal traces |
| 0.5 mm | 0.50 mm | Power traces (VBUS, +3.3V, GND stubs) |

### Via dimension presets

| Preset | Pad Ø | Drill Ø | Notes |
|---|---|---|---|
| Default | — | — | Net-class driven |
| Standard | 0.70 mm | 0.30 mm | Smallest reliable via for standard fabs |

### Differential pair presets

| Preset | Trace width | Gap | Via gap |
|---|---|---|---|
| Default | — | — | — |
| USB FS  | 0.30 mm | 0.30 mm | 0.50 mm |

The USB differential pair preset (0.3 mm / 0.3 mm gap) is sized for the USB_D+ / USB_D−
traces. At USB Full Speed (12 Mbit/s) the signal rise time is ~4 ns; for a 2-layer FR4
board a 0.3 mm trace over 1.51 mm FR4 gives a characteristic impedance of approximately
90 Ω single-ended (≈ 90 Ω differential), close to the USB 90 Ω differential target.

---

## 3 — Teardrop Settings

Teardrops are enabled globally:

| Location | Enabled |
|---|---|
| PTH pads | Yes |
| SMD pads | Yes |
| Vias | Yes |
| Track ends | No |

Teardrop geometry (all types):

| Parameter | Value |
|---|---|
| Height ratio | 1.0 (100% of track width) |
| Length ratio | 0.5 (50% of via/pad diameter) |
| Max height | 2.0 mm |
| Max length | 1.0 mm |
| Allow two-track teardrops | Yes |
| Curved segments | 0 (straight chamfer) |

Teardrops reduce mechanical stress at the pad-to-trace junction and improve DFM
(manufacturing yield) by preventing drill-breakout from tearing the annular ring.

---

## 4 — DRC Rule Severities (selected)

| Rule | Severity  | Notes |
|---|---|---|
| `clearance` | error | Hard stop |
| `unconnected_items` | error | All nets must be routed |
| `courtyards_overlap` | error | No component overlap |
| `solder_mask_bridge` | error | |
| `shorting_items` | error | |
| `missing_courtyard` | ignore | Some library parts lack courtyards |
| `footprint_type_mismatch` | ignore | |
| `duplicate_footprints` | warning | |
| `track_dangling` | warning | Acceptable during layout-in-progress |
| `missing_footprint` | warning | |
| `hole_to_hole` | warning | |
| `silk_over_copper` | warning | |

---

## 5 — Plot / Gerber Output Settings

Output format: **Gerber** (format 1).
Gerber extensions: **standard** (no non-standard extensions).
Gerber attributes: **enabled** (X2 attributes for fab).
Gerber job file: **enabled**.
Black & white plot: **yes** (drill map / PDF).
DNP parts on fab layer: **crossed out** (sketchDNP + crossoutDNP = yes).

---

## Checklist

| Item | Functional impact | BOM impact |
|---|:---:|:---:|
| Board stackup defined (1.6 mm, 2-layer) | None (no copper yet) | No |
| Design rules set | None (enforced at DRC time) | No |
| Track/via presets added | None | No |
| Teardrop settings configured | None | No |
| DRC severities configured | None | No |
| Plot/Gerber settings configured | None | No |

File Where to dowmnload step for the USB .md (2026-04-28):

# Info

https://www.we-online.com/en/components/products/INPUT_OUTPUT_WR_USB_MINI_MICRO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

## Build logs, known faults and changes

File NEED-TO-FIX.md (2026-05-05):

# DRC Fix Plan

All errors come from the `kicad-cli pcb drc` run in CI.  
Target: **0 errors** so the pipeline passes on `main`.

---

## Error Summary

| # | Rule | Count | Severity | Root cause |
|---|---|---|---|---|
| 1 | `via_diameter` | 28 | Error | All vias placed at 0.6 mm; board min is 0.7 mm |
| 2 | `unconnected_items` | 20 | Error | GND and +3.3V net segments have broken connections |
| 3 | `starved_thermal` | 2 | Error | VBUS zone thermal relief has only 1 spoke; min is 2 |

---

## Fix 1 — Via diameter (28 errors)

**All vias are 0.6 mm drill / 0.6 mm annular; board minimum is 0.7 mm.**

### Option A — Resize all vias to 0.7 mm (recommended for JLCPCB 2-layer)

1. Open `tproject.kicad_pcb` in KiCad PCB Editor.
2. `Edit → Find` or press `T` to open inspector; alternatively use `Edit → Change Footprint`.
3. Better: use **Scripting Console** (`Tools → Scripting Console`):
   ```python
   import pcbnew
   board = pcbnew.GetBoard()
   for track in board.GetTracks():
       if track.GetClass() == 'PCB_VIA':
           track.SetWidth(pcbnew.FromMM(0.8))   # outer diameter
           track.SetDrillValue(pcbnew.FromMM(0.4))  # drill
   pcbnew.Refresh()
   ```
   This sets all vias to 0.8 mm / 0.4 mm drill — well within JLCPCB standard rules (min via 0.3 mm drill, 0.6 mm pad).
4. Run DRC again to confirm `via_diameter` errors are gone.
5. Save → commit.

### Option B — Lower board minimum (only if fab supports it)

1. `File → Board Setup → Design Rules → Constraints`
2. Change **Minimum via diameter** from `0.7 mm` to `0.6 mm`.
3. Save → run DRC → commit.
> ⚠ JLCPCB standard process minimum is 0.6 mm pad (0.3 mm drill), so Option B is technically valid but leaves no margin. Option A is safer.

---

## Fix 2 — Unconnected items (20 errors)

**Net segments on GND and +3.3V are not electrically joined — ratsnest lines visible in PCB editor.**

Affected nets: `GND` (17 gaps), `+3.3V` (2 gaps), `VBUS` (1 gap to U2 pad 3).

### Step-by-step

1. Open `tproject.kicad_pcb`.
2. Run `Inspect → Design Rules Checker` (or press `D` shortcut).
3. In the DRC dialog click **Run DRC** → switch to the **Unconnected** tab.
4. Double-click each entry — the PCB editor will zoom to and highlight the two disconnected endpoints.
5. For each gap:
   - If the gap is tiny (< 0.1 mm): the track ends do not quite touch — use `Route → Interactive Router` (`X`) to draw a short closing segment, or drag the track endpoint to snap it.
   - If the gap is a missing segment: route the ratsnest manually with `X`.
   - If the gap crosses layers: add a via and route on B.Cu.
6. Specific items to check:
   | Net | From | To | Note |
   |-----|------|----|------|
   | GND | `C1 pad 2` | track near J1 | Short stub, re-route |
   | GND | `C2 pad 2` | track near U2 | Re-route via B.Cu GND plane |
   | GND | multiple track stubs | adjacent tracks | Drag endpoints to merge |
   | +3.3V | track stubs near decoupling caps | power rail | Route closing segment |
   | VBUS | Zone on F.Cu | `U2 pad 3` | Add a short track from U2 pad 3 to VBUS zone |
7. After routing, re-run DRC and confirm **0 unconnected items**.
8. Refill copper zones: `Edit → Fill All Zones` (`B`).

---

## Fix 3 — Starved thermal (2 errors)

**VBUS zone has thermal relief pads connected by only 1 spoke; zone requires 2.**

Affected pads:
- `J1 pad 1 [VBUS]` at (68.9, 67.325)
- `C1 pad 1 [VBUS]` at (63.35, 70.5)

### Option A — Reduce zone min spoke count to 1

1. Click on the **VBUS zone** (filled copper area on F.Cu).
2. Press `E` → Zone Properties.
3. Under **Thermal relief** → **Minimum thermal relief spoke count** → change from `2` to `1`.
4. Refill zones (`B`) → run DRC.

### Option B — Override to solid connection on those pads

1. Double-click `J1` → open footprint properties → select **Pad 1**.
2. In **Pad Properties → Connection** → override to **Solid**.
3. Repeat for `C1 pad 1`.
4. Refill zones (`B`) → run DRC.

> Option A is simpler. Option B gives better thermal/electrical performance for a power pad but is overkill for a small VBUS decoupling cap.

---

## Verification checklist

- [ ] DRC reports **0 errors** locally
- [ ] `git add tproject.kicad_pcb && git commit -m "pcb: fix DRC errors (via size, unconnected, thermals)"`
- [ ] Push to `main` — CI pipeline passes
- [ ] Re-export Gerbers and replace files in `manufacturing/`
- [ ] Re-export pick-and-place `tproject-top-pos.csv`
- [ ] Commit updated manufacturing files

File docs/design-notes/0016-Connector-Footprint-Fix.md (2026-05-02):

# 0016 — Connector Footprint Fix: Conn_01x04 (J2, J3, J4)

**Date:** 2026-05-02
**Status:** Implemented
**References:** Design note 0005 (Power Supply and Connectors), design note 0007 (Footprint Assignment); git commit `3de90ea`

---

## Summary

All three 4-pin single-row connectors (J2, J3, J4) were assigned the wrong footprint
during the footprint assignment step (0007). They carried a 1.00 mm pitch SMD footprint
instead of the correct 2.54 mm pitch through-hole footprint. This caused the PCB 3D
view to render tiny SMD land patterns in place of standard pin headers.

| Ref | Value | Wrong footprint (before) | Correct footprint (after) |
|-----|---|---|---|
| J2  | Conn_01x04 | `Connector_PinHeader_1.00mm:PinHeader_1x04_P1.00mm_Vertical_SMD_Pin1Right` | `Connector_PinHeader_2.54mm:PinHeader_1x04_P2.54mm_Vertical` |
| J3  | Conn_01x04 | `Connector_PinHeader_1.00mm:PinHeader_1x04_P1.00mm_Vertical_SMD_Pin1Right` | `Connector_PinHeader_2.54mm:PinHeader_1x04_P2.54mm_Vertical` |
| J4  | Conn_01x04 | `Connector_PinHeader_1.00mm:PinHeader_1x04_P1.00mm_Vertical_SMD_Pin1Right` | `Connector_PinHeader_2.54mm:PinHeader_1x04_P2.54mm_Vertical` |

---

## 1 — Root Cause

During footprint assignment the library browser returned the 1.00 mm SMD pin header as
the first match for `PinHeader_1x04`. The correct 2.54 mm through-hole variant sits in a
different library (`Connector_PinHeader_2.54mm`) and was not selected. Both libraries
exist in KiCad 9's standard footprint library set, but KiCad 9 changed the ordering and
default display of search results compared to earlier KiCad versions, making the SMD
variant appear first.

---

## 2 — Correct Footprint Specification

| Parameter | Value |
|---|---|
| Library | `Connector_PinHeader_2.54mm` |
| Footprint name | `PinHeader_1x04_P2.54mm_Vertical` |
| Pitch | 2.54 mm (0.1 in) |
| Rows × Pins | 1 × 4 |
| Package style  | Through-hole, vertical |
| Pad drill | 1.0 mm nominal |
| Pad size | 1.7 × 1.7 mm nominal |

---

## 3 — Fix Applied

The `Footprint` property was corrected in `tproject.kicad_sch` for all three connector
instances. No net connections, pin assignments, or component values were altered. The PCB
layout requires an **Update PCB from Schematic** pass to replace the SMD land patterns
with the 2.54 mm through-hole footprints and reposition pads accordingly.

### Steps to update PCB after this change

1. Open `tproject.kicad_pcb` in KiCad PCB editor.
2. Run **Tools → Update PCB from Schematic…** (or press `F8`).
3. Confirm the three footprint changes for J2, J3, J4.
4. Re-place J2, J3, J4 at their intended board positions (see design note 0012 for
   reference positions).
5. Re-run DRC to verify no clearance violations are introduced.

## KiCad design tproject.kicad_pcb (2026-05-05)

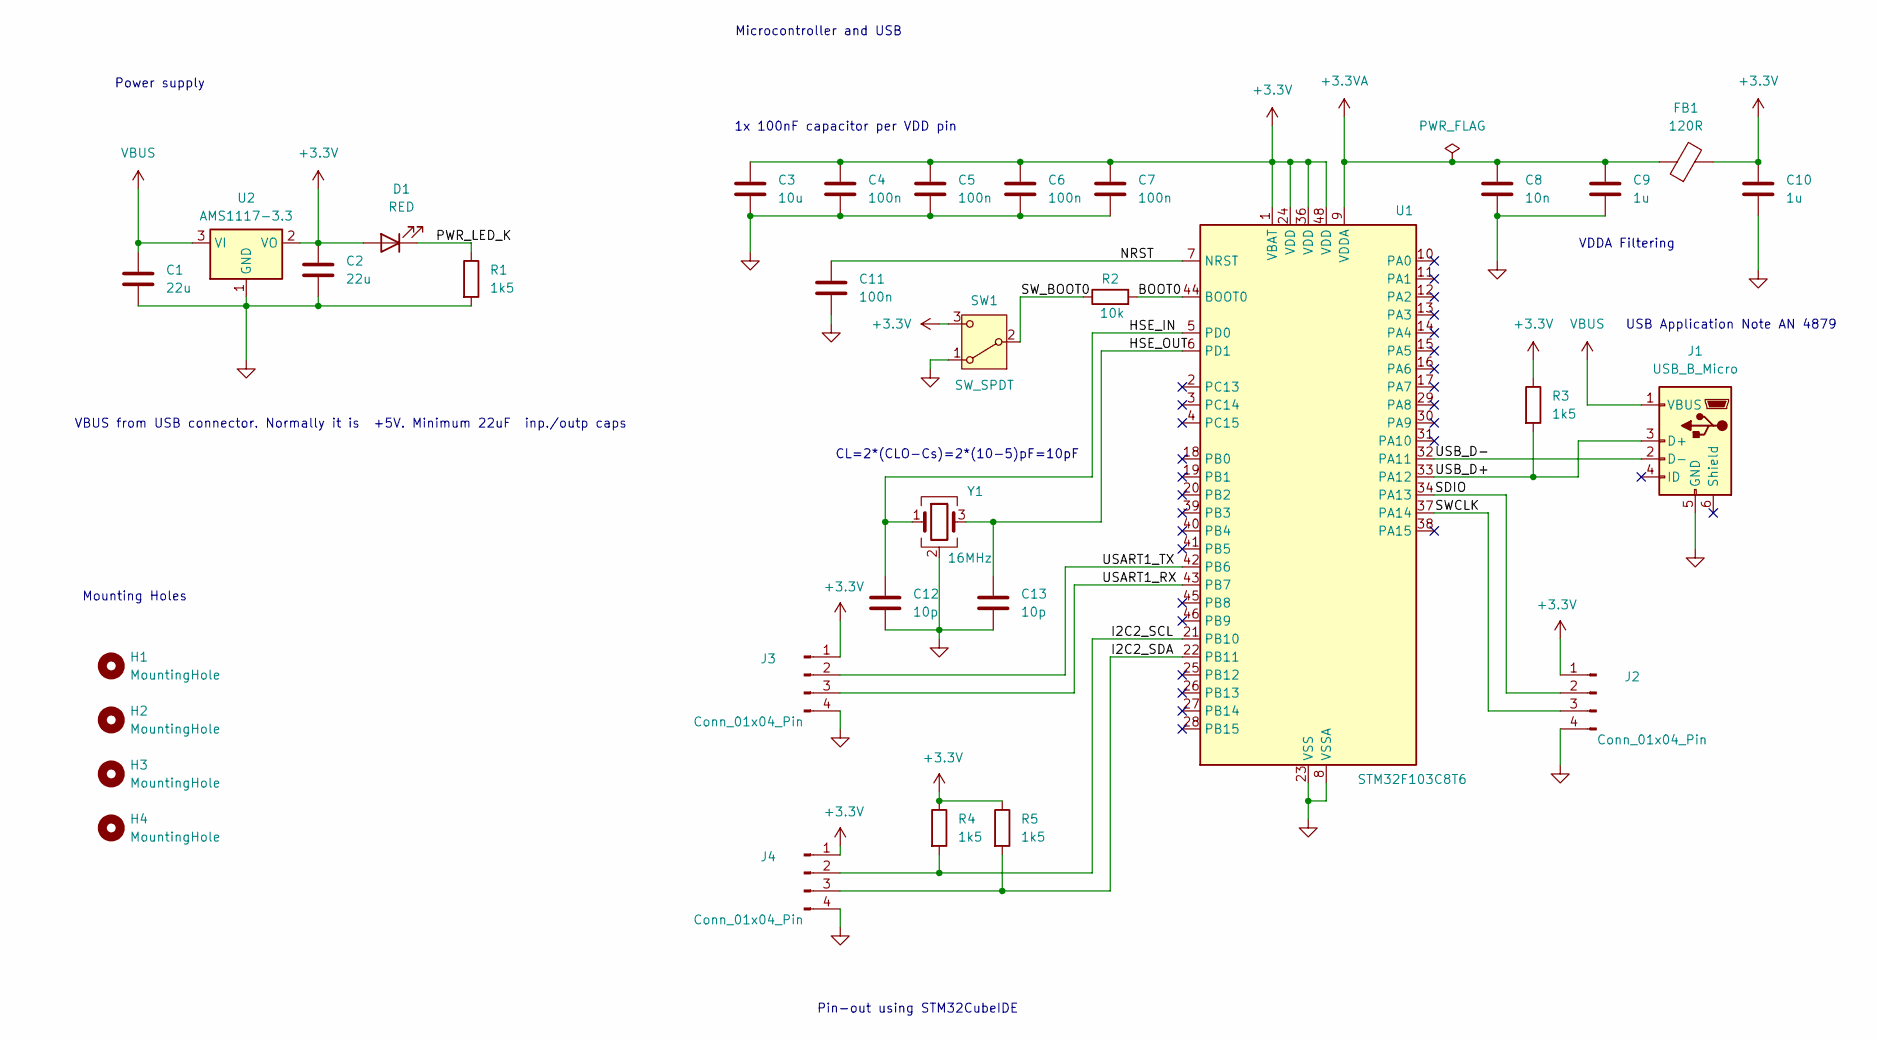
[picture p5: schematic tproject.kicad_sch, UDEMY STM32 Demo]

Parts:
C1, C2: 22u; C_0805_2012Metric
C3: 10u; C_0603_1608Metric
C4, C5, C6, C7, C11: 100n; C_0402_1005Metric
C8: 10n; C_0402_1005Metric
C9, C10: 1u; C_0402_1005Metric
C12, C13: 10p; C_0402_1005Metric
D1: RED; LED_0603_1608Metric
FB1: 120R; L_0603_1608Metric
H1, H2, H3, H4: MountingHole; MountingHole_2.2mm_M2
J1: USB_B_Micro; USB_Micro-B_Wuerth_629105150521
J2, J3, J4: Conn_01x04_Pin; PinHeader_1x04_P2.54mm_Vertical
R1, R3, R4, R5: 1k5; R_0402_1005Metric
R2: 10k; R_0402_1005Metric
SW1: SW_SPDT; SW_SPDT_PCM12
U1: STM32F103C8T6; LQFP-48_7x7mm_P0.5mm
U2: AMS1117-3.3; SOT-223-3_TabPin2
Y1: 16MHz; Crystal_SMD_3225-4Pin_3.2x2.5mm

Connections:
+3.3V: C2.1, C3.1, C4.1, C5.1, C6.1, C7.1, C10.1, D1.2 (A), FB1.2, J2.1, J3.1, J4.1, R3.1, R4.1, R5.1, SW1.3 (C), U1.1 (VBAT), U1.24 (VDD), U1.36 (VDD), U1.48 (VDD), U2.2 (VO)
+3.3VA: C8.1, C9.1, FB1.1, U1.9 (VDDA)
/BOOT0: R2.2, U1.44 (BOOT0)
/HSE_IN: C12.1, U1.5 (PD0), Y1.1
/HSE_OUT: C13.1, U1.6 (PD1), Y1.3
/I2C2_SCL: J4.2, R4.2, U1.21 (PB10)
/I2C2_SDA: J4.3, R5.2, U1.22 (PB11)
/NRST: C11.1, U1.7 (NRST)
/PWR_LED_K: D1.1 (K), R1.1
/SDIO: J2.2, U1.34 (PA13)
/SWCLK: J2.3, U1.37 (PA14)
/SW_BOOT0: R2.1, SW1.2 (B)
/USART1_RX: J3.3, U1.43 (PB7)
/USART1_TX: J3.2, U1.42 (PB6)
/USB_D+: J1.3 (D+), R3.2, U1.33 (PA12)
/USB_D-: J1.2 (D-), U1.32 (PA11)
GND: C1.2, C2.2, C3.2, C4.2, C5.2, C6.2, C7.2, C8.2, C9.2, C10.2, C11.2, C12.2, C13.2, J1.5 (GND), J2.4, J3.4, J4.4, R1.2, SW1.1 (A), U1.8 (VSSA), U1.23 (VSS), U1.35 (VSS), U1.47 (VSS), U2.1 (GND), Y1.2 (G), Y1.4 (G)
VBUS: C1.1, J1.1 (VBUS), U2.3 (VI)

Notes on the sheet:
CL=2*(CLO-Cs)=2*(10-5)pF=10pF
Mounting Holes
Pin-out using STM32CubeIDE
Microcontroller and USB
VBUS from USB connector. Normally it is +5V. Minimum 22uF inp./outp caps
USB Application Note AN 4879
Power supply
1x 100nF capacitor per VDD pin
VDDA Filtering

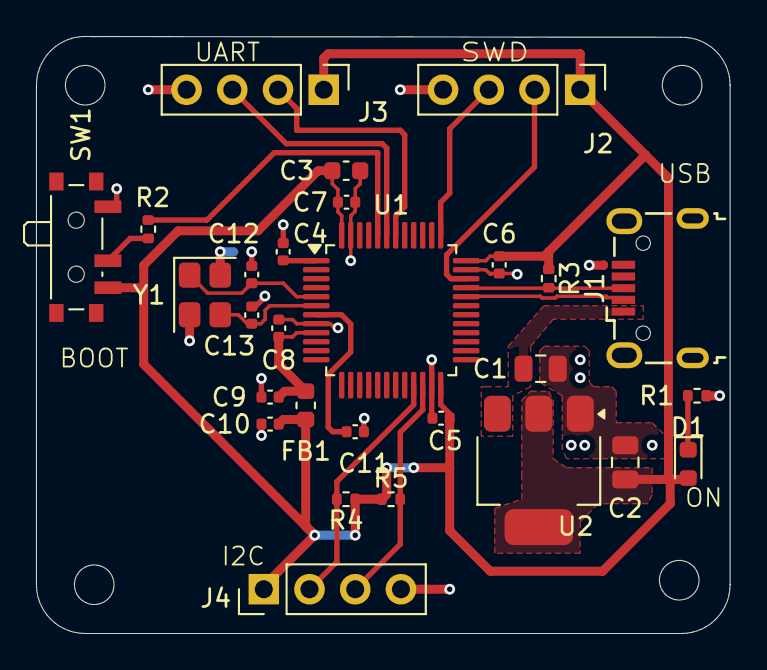
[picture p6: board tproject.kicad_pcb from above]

Board: 2 copper layers, 38.5 x 33.2 mm, 32 parts (0 on the bottom side), 18 nets.

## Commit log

2026-04-25 Initial commit: KiCad project with .gitignore
    [tproject.kicad_pcb, tproject.kicad_sch]
2026-04-25 Add design note 0001: Power decoupling network for STM32F103C8T6
2026-04-25 Add scripts/gen_design_note.py: auto-generate design notes from KiCad schematic
2026-04-25 Add design_note_to_kicad.py: generate .kicad_sch/.kicad_pro from design note BOM tables
2026-04-25 Restore original schematic and project files
    [tproject.kicad_sch]
2026-04-25 Add NRST filter and BOOT0 switch circuit (C9, R1, SW1)
    [tproject.kicad_sch]
2026-04-26 Add HSE crystal oscillator circuit (Y1 16MHz, C10/C11 10p) and design note 0003
    [tproject.kicad_sch]
2026-04-26 Add USB Micro-B interface circuit (J1, R2 1k5 D+ pull-up) and design note 0004
    [tproject.kicad_sch]
2026-04-26 Add 3.3V LDO regulator, power LED, I2C pull-ups, and breakout connectors (U2, C12/C13, D1, R3-R5, J2-J4) and design note 0005
    [tproject.kicad_sch]
2026-04-26 Add PWR_FLAG ERC fix, title block, schematic annotations, and component repositioning — design note 0006
    [tproject.kicad_sch]
2026-04-26 Re-annotate capacitors and resistors in positional order and update design note 0006
    [tproject.kicad_sch]
2026-04-26 Assign footprints to all schematic symbols and add design note 0007
    [tproject.kicad_sch]
2026-04-26 Configure PCB board setup (stackup, design rules, track/via presets, teardrops) and add design note 0008
    [tproject.kicad_pcb]
2026-04-27 Place all 26 components on PCB (initial floorplan) and add design note 0009
    [tproject.kicad_pcb]
2026-04-27 Refine USB and SWD/SWO circuit component placement and add design note 0010
    [tproject.kicad_pcb]
2026-04-28 Replace SW1 with SMD PCM12 footprint, add Wurth USB STEP model, and add design note 0011
    [629105150521 (rev1).stp, tproject.kicad_pcb, tproject.kicad_sch]
2026-04-29 Refine switch, connector, and peripheral circuit placement and add design note 0012
    [tproject.kicad_pcb]
2026-04-29 Finalize power supply cluster placement (U2, C1-C3, C5-C7, D1, R1) and add design note 0013
    [tproject.kicad_pcb]
2026-04-29 Add board outline (38.54x33.17mm), 4x M2 mounting holes, adjust 8 components and add design note 0014
    [tproject.kicad_pcb, tproject.kicad_sch]
2026-05-02 Route decoupling caps and HSE crystal (39 tracks, B.Cu fill) and add design note 0015
    [tproject.kicad_pcb]
2026-05-02 Fix Conn_01x04 footprint: 1.00mm SMD → 2.54mm through-hole (J2, J3, J4)
    [tproject.kicad_sch]
2026-05-02 Add design note 0016: Conn_01x04 footprint fix (J2, J3, J4)
2026-05-02 Route all signal nets (52 segs, F.Cu) and add design note 0017
    [tproject.kicad_pcb]
2026-05-05 Add design note 0020: BOM and Gerber export — final stage
    [tproject-B_Cu.gbr, tproject-B_Mask.gbr, tproject-B_Paste.gbr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]
2026-05-05 the end of the course
    [tproject.csv, tproject.kicad_pcb, tproject.kicad_sch]
2026-05-05 Add README.md with board render, BOM, Gerbers, and design notes index
2026-05-05 Update te CI to have ERC DRC and PDF Schematic
2026-05-05 ci: add GitHub Actions workflow (ERC, DRC, schematic PDF)
2026-05-05 ci: filter ERC to errors only, suppress lib_symbol_issues warnings
2026-05-05 ci: filter DRC to errors only, suppress lib_footprint_issues warnings
